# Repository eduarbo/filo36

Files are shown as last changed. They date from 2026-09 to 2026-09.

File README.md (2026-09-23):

# Flan36

**36 keys. Piantor angles. Your keycaps, your frames.**

**[Explore and customize in 3D →](https://eduarbo.github.io/flan36/)** · **[Parts and buying links →](docs/parts.md)** · **[Edit in FreeCAD →](docs/freecad.md)**

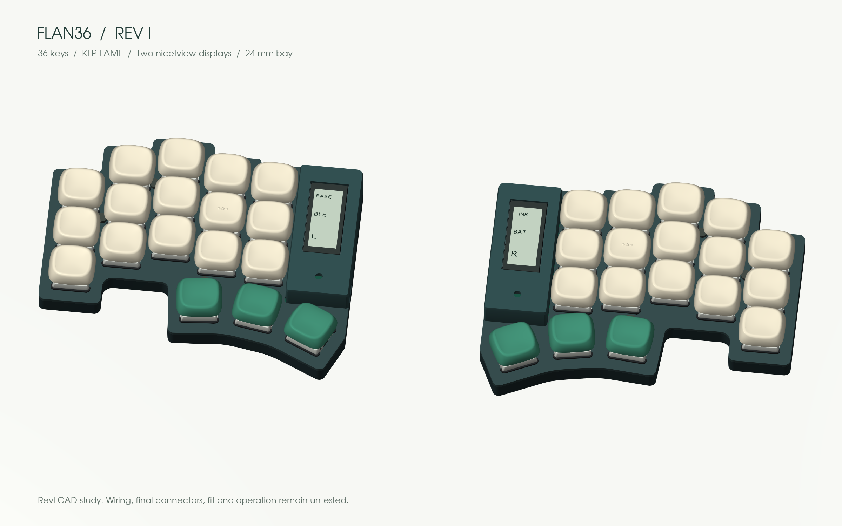
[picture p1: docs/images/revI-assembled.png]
Flan36 revI with interchangeable display frames and original KLP Lamé keycaps


*RevI: key-aligned local curves, three interchangeable cases, optional exposed display stack, magnetic frames and one cradle for two battery sizes. Physical fit untested.*

**[Themes and print kits](docs/themes-printing.md)** — Sixteen coordinated themes, personal keycap palettes, linked rim/frame colors and selected STL/3MF parts.

**[Case variants](docs/cases.md)** — Solid, Color rim and Terrace; actual meshes in the explorer.

Flan36 is a low-profile wireless split keyboard in development by [Eduardo Ruiz](https://github.com/eduarbo). It keeps Piantor’s key centers and angles, with five columns and three thumb keys per half.

- **KLP Lamé choices:** all 38 Choc-stem variants catalogued; 28 qualify in at least one position. The viewer checks complete combinations and exports a configuration for FreeCAD.
- **Magnetic frames:** Cartridge, Arcade, Mecha, Kintsugi, Handheld, Retro TV and Cyberpunk, with multicolor relief palettes, plus three plain styles and separate body colors per half. Opaque skirts hide the stack; the display has its own support.
- **Keycap colors:** paint all keys, rows, columns or individual keys; save and share your own palettes.
- **Free tools:** KiCad for electronics, FreeCAD for the case, StepUp for exchange. Editable source, STEP/STL, offline viewer and GLB included.
- **Intended hardware:** Choc v1 hot-swap, two nice!nano controllers and two nice!view displays. One display remains the fallback.

**Status: digital prototype, not ready to manufacture.** Both PCB studies have zero geometric DRC violations and 104 unconnected items each. Routing, exact connectors, printed retention, BLE and power consumption still require work. The visual model does not establish hardware compatibility.

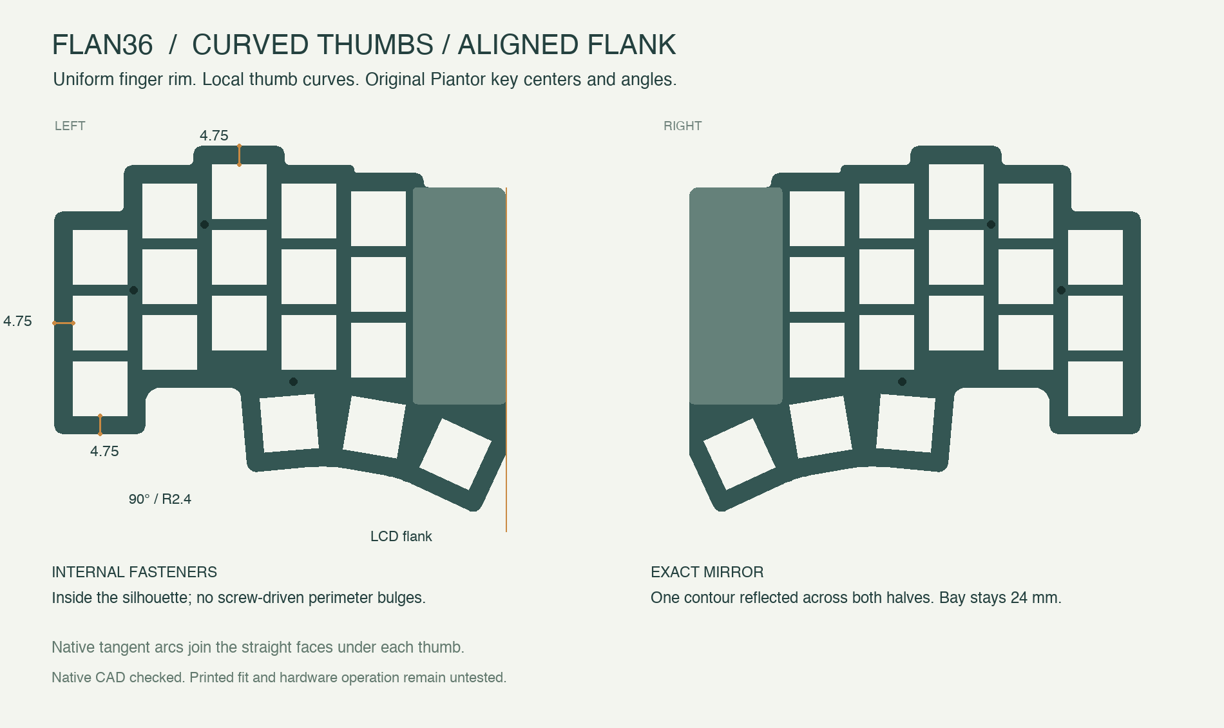
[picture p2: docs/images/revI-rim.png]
Measured rim and mirrored case halves


**[Keycaps and frames](docs/customize.md) · [Design](docs/design.md) · [Build](docs/build.md) · [CAD files](docs/cad.md) · [Progress](docs/progress.md)**

Based on [Piantor by beekeeb](https://github.com/beekeeb/piantor), with [KLP Lamé by braindefender](https://github.com/braindefender/KLP-Lame-Keycaps). [Credits and licenses](ATTRIBUTION.md). [Contributing](CONTRIBUTING.md).

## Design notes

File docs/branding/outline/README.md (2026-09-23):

# Flan36 Outline — SVG kit

The selected Outline concept is now an editable, font-free vector. Its symbol and six letters are closed filled Bézier paths; the four internal holes remain open. One chosen logo, supplied as a complete mark, symbol and lettering.

| File | Use | SVG page width |
| --- | --- | --- |
| `flan36-outline-master.svg` | Editable source; symbol and each letter have a named path | 30 mm |
| `flan36-outline-black.svg` | Complete logo, one ink; starting point for graphics import | 30 mm |
| `flan36-outline-symbol-black.svg` | Symbol alone, one ink; starting point for a small case/PCB mark | 12 mm |
| `flan36-outline-wordmark-black.svg` | Lettering alone, already converted to paths | 30 mm |

Backgrounds are transparent. `preview.svg` is a presentation sheet, **not** a manufacturing master; it presents the same logo on a light background. The logo SVGs have no fonts, raster images, live strokes, masks or external resources.

## PCB: KiCad

Import the black logo or symbol through **File → Import → Graphics**, set scale to **1**, select **F.SilkS** (or B.SilkS for a back-side mark), and group the imported items. Inspect the actual size and back-side orientation. Keep the mark clear of exposed pads, existing legends and mounting holes; check the fabricator's minimum line/space rules at the final scale. [KiCad graphics-import documentation](https://docs.kicad.org/10.0/en/pcbnew/pcbnew.html#importing-vector-graphics).

These are page widths with a tiny artboard margin, not approved placement dimensions. No logo is placed on the keyboard PCB by this kit. KiCad placement and final fabrication output still need checking.

## Case: FreeCAD

Import the black logo or symbol as **SVG as geometry (importSVG)**. The imported paths can form faces for an emboss or a pocket. Select the symbol alone for a compact mark, or all seven faces for the complete logo. [FreeCAD SVG workflow](https://github.com/FreeCAD/FreeCAD-documentation/blob/main/wiki/Import_text_and_geometry_from_Inkscape.md).

The supplied black logo, symbol and wordmark were imported headlessly into FreeCAD 1.1.3: dimensions, counters and valid trial extrusions were checked. This does not qualify a cut in a case wall. Choose the final placement and relief depth against the actual wall, ribs, battery and joining features. No case geometry is changed by this kit.

## Edit and regenerate

Edit `flan36-outline-master.svg` in a vector editor. For the repository generator, keep the seven named top-level paths, explicit absolute M/C/Z commands, no transforms and `fill-rule="evenodd"`; closed cubic contours keep the import path simple.

From the repository root, use a Python environment with `tools/requirements-branding.txt`:

```sh
python tools/build_outline_logo.py --png --package
python tools/check_outline_logo.py
python tools/freecad/run_macos.py tools/freecad/check_outline_logo.py
```

CairoSVG needs the Cairo system library for PNG rendering and raster readback. On macOS with Homebrew Cairo, prefix the first two commands with `DYLD_FALLBACK_LIBRARY_PATH=/opt/homebrew/lib`. The last command uses the existing macOS FreeCAD installation and opens no GUI. On other platforms, run `tools/freecad/check_outline_logo.py` in a FreeCAD Python environment.

`--trace` intentionally recreates the master from the selected concept and **replaces manual master edits**. Normal regeneration omits that flag. The vector trace uses the bottom-left monochrome reference from `docs/images/branding/flan36-caramel-outline.png`; earlier concept boards remain historical references.

The kit contains SVG art, this guide, a hash manifest and the repository license. It contains no placed PCB artwork, case cut, G-code or print-process approval. [Source and provenance](https://github.com/eduarbo/flan36/blob/main/design/branding-outline-vectors.json).

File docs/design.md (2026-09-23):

# Design

Keep Piantor’s angles, a thin key area and serviceable electronics.

| Choice | Reason |
|---|---|
| 3 × 5 + 3 keys per half | Remove the unused outer column without changing the remaining centers or angles |
| Choc v1 hot-swap | Low-profile, replaceable switches |
| Two nice!nano controllers, intended ZMK firmware | Wireless halves and host connection; USB-C for charging/programming |
| Battery below controller, display above | Concentrate electronics in the existing 24 mm bay |
| Independent internal supports | Neither the battery pouch nor display glass carries the stack |
| Interchangeable opaque display frames | Hide the stack and customize its appearance without moving keys |

## The stack

The insulating saddle stays below the PCB. The cell and a narrow removable cage pass through a **12.5 × 33.6 mm opening**. One cavity accepts the nominal Adafruit 1570 and 301230 envelopes; select either in the viewer or FreeCAD. The model reserves two 105 mm lead paths, but actual terminal positions, wire diameter and strain relief still need measurement. [Battery dimensions and sources](parts.md#battery).

The case is **116.75 × 94.57 mm per half**. Five stepped column tops, an orthogonal pinky foot and a shallow rounded recess follow the reference. Straight lower faces remain parallel to each thumb key, joined by **local tangent arcs**. The outside thumb flank stops at the LCD panel edge. The 21 control corners use locally bounded radii, including R2.4 finger corners where space permits. Straight exposed faces retain their **4.75 mm** copper allowance. Fasteners stay within existing material. Both halves are exact mirrors; all 36 switch centers and angles remain unchanged.

Choose [Solid, Color rim or Terrace](cases.md). These are different base/plate geometries, compatible with the same stack and ten display frames. The printed display cover can be omitted while retaining the display and structural supports.

Measured exterior rim

The key plate stays at **7.6 mm**, plain frames at **16.6 mm**, themed relief at **17.2 mm**. The electronics bay remains **24 mm wide**; illustrative feet add 1.2 mm. The frame ends at Y=67 mm while the low base/plate continue to the thumb. The power-switch reference is now recessed 0.1 mm inside the straight X=135 mm flank.

The frame now shares the case's **R2.4 north/outside corner** beside USB, including its tangency points. The former independent R1.2 frame corner projected about **0.497 mm** beyond that curve. The cavity, plate clearance and beveled lips follow the corrected corner; the case and PCB outlines stay unchanged.

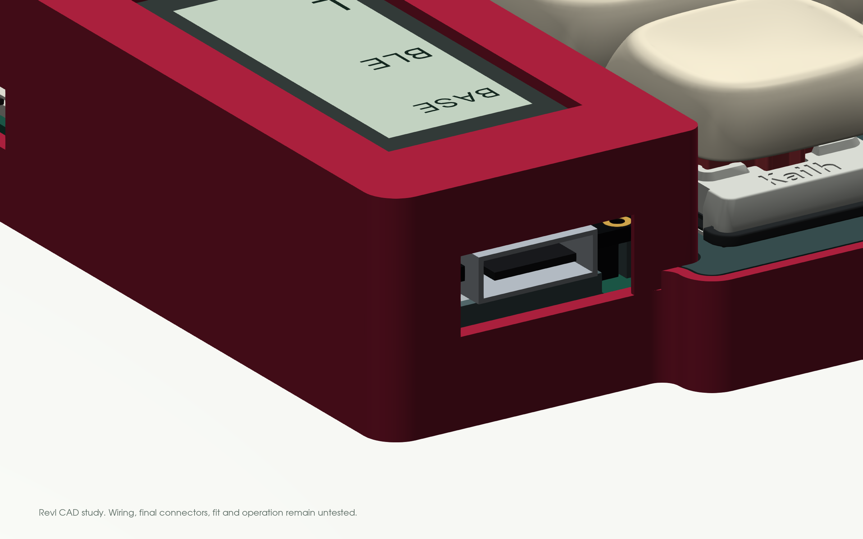
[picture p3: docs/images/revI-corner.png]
Shared corner on the actual Color rim and Smooth frame meshes


### Can the stack be thinner?

**The current height is not a proven minimum.** The completed
[slim support study](slim-mount-study.md) supersedes the preliminary left-half
height check: it covers both halves, all 10 frames and both battery profiles.
Dimensions below start at the case bottom, excluding feet.

| Configuration | Plain cover | Decorated cover | Status |
| --- | ---: | ---: | --- |
| Reference | 16.6 mm | 17.2 mm | Static modeled checks clear; retained |
| Lower display candidate | 15.6 mm | 16.2 mm | Static modeled checks clear; experimental |
| Rejected limit | 14.8 mm | 15.4 mm | Roof intersects the JST connector by 0.3 mm |

The lower candidate moves the display bottom from 14.2 to **12.4 mm**, leaving
**0.82 mm** between the modeled MCU and display and **0.5 mm** above the JST.
Actual header engagement and electrical continuity remain unqualified. With the
selected KLP Lamé keycaps, total height remains **17.87 mm** in all three
recipes; lowering the cover does not lower the highest point.

All three recipes have a service conflict: lifting the display and sled together
crosses the modeled battery leads at **0.5–2 mm**. Lead routing or the removal
sequence must change and be rechecked before physical qualification. The native
source retains the reference height.

Fusing the three washers into each plate removes **six loose parts** across the
keyboard while preserving their seats. Optional base/saddle fusion removes two
more, at the cost of independent saddle replacement. Both changes have **zero
height reduction**. [Study geometry and full findings](slim-mount-study.md) include
the rejected limit for comparison; printed fit remains unqualified. The
[earlier height report](../validation/revI-stack-study.json) remains as historical
evidence.

### Magnetic frame, independent structure

Three captive **Ø2 × 3 mm magnets** in the base attract three captive **Ø2 × 4 mm steel pins** in each frame. Shallow guides locate the cover; it lifts vertically. The frame carries no battery or display load. Five internal M2 fasteners per half retain the plate/PCB independently, with no added perimeter lobes. Three use 6 mm shafts; the two hidden under the frame use 4 mm shafts.

The inserts are enclosed by a pause-and-insert print sequence. Force through the nominal **0.9 mm gap**, north-edge peel, print capture and magnet temperature remain physical tests. [Assembly sequence and coupons](build.md#magnetic-frame-and-service).

## One or two displays

The CAD shows two nice!view displays; one on the left remains the fallback if integration becomes impractical. The intended central display shows primary keyboard state. A peripheral display may show its own battery/link state; mirrored layer information is not promised. [nice!view setup](https://nicekeyboards.com/docs/nice-view/getting-started/).

nice!view is a reflective memory LCD. OLED improves dark-room visibility but uses more power; e-paper favors mostly static images and needs different mounting and firmware. These are alternatives to redesign around, not drop-in replacements. [Display specifications](https://nicekeyboards.com/docs/nice-view/).

## Modularity

Switch sockets, removable controller/display connectors, a battery connector, magnetic covers and independent screws allow servicing after initial soldering. The frames are separate from the display support. Service electronics with power off and USB disconnected; removable connectors are not a proposal for live module hot-plugging.

## CAD views

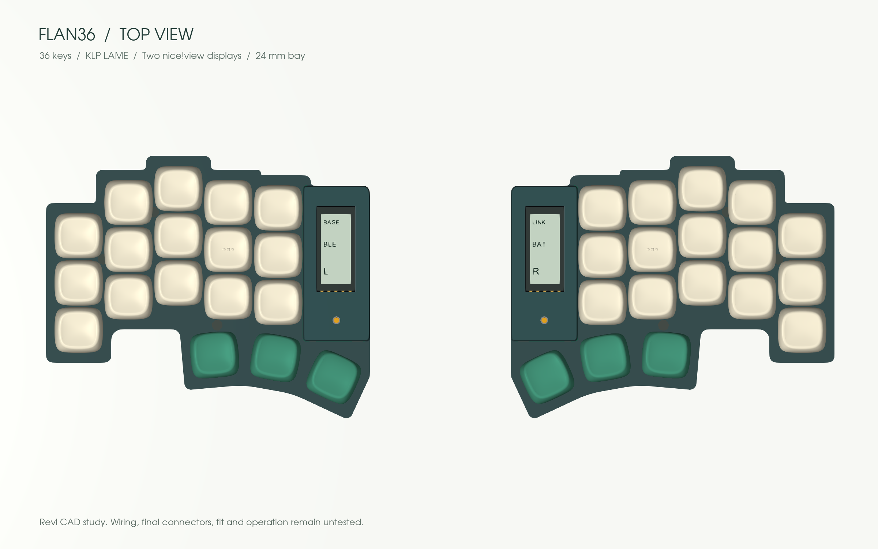
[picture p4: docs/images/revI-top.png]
RevI top view with 36 KLP Lamé keycaps and two display frames


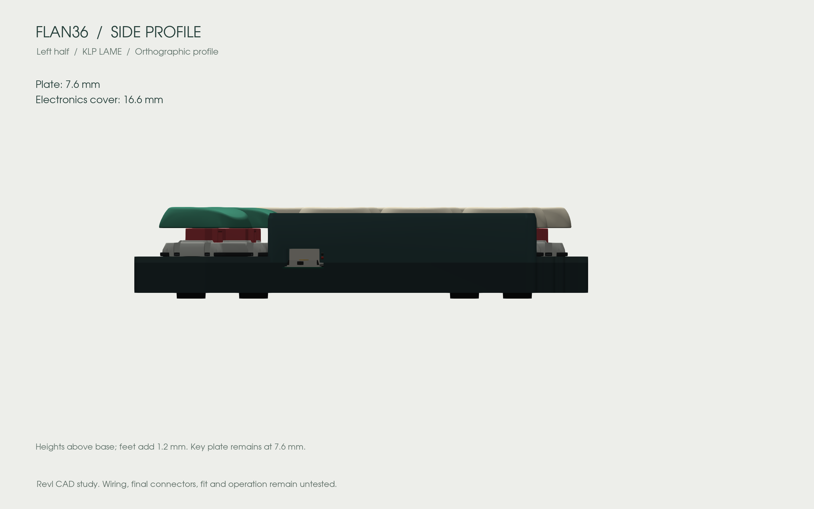
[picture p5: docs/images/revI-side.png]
RevI side profile


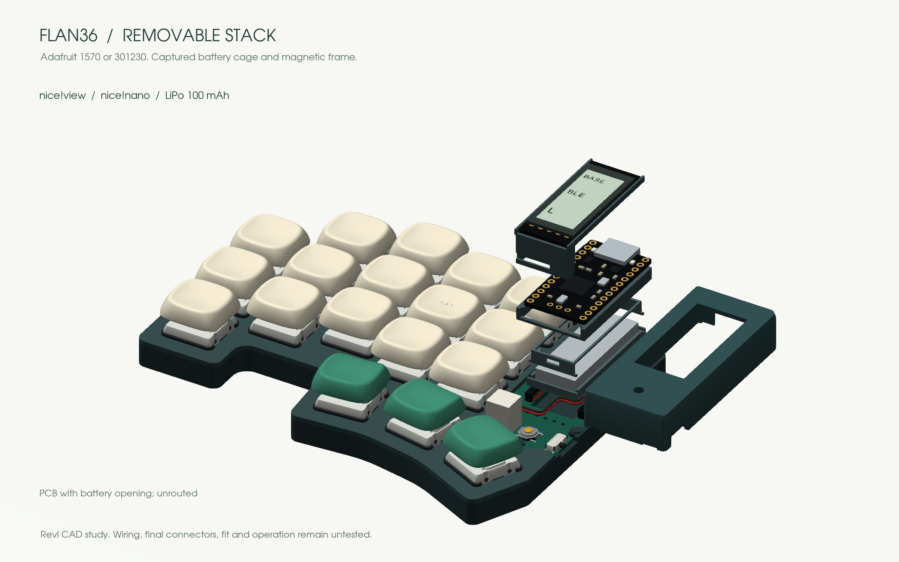
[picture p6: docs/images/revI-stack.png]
RevI exploded stack with removable opaque cover


These views come from the exported geometry. Electronics, switch bodies, keycap seating, screws and feet are nominal references. No physical assembly or functioning keyboard is established by the renders. [Source files and remaining work](cad.md).

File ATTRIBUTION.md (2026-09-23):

# Credits and licenses

Flan36 is a derivative project developed by Eduardo Ruiz. Its case and wireless electronics are developed here; its key layout comes from Piantor. There is no implied affiliation or certification by beekeeb or component manufacturers.

| Material | Author / source | License and changes |
|---|---|---|
| `sources/piantor/*.kicad_pcb` | beekeeb / Leo, [Piantor](https://github.com/beekeeb/piantor), commit `cd847afb4f9a86e8c1c8e36f243140644013afb2` | GPL-3.0; unchanged original copies |
| Choc footprint `keyswitches:Kailh_socket_PG1350_optional` | daprice, [keyswitches.pretty](https://github.com/daprice/keyswitches.pretty) | CC-BY-SA-4.0; notice in [LICENSES/Keyswitches.md](LICENSES/Keyswitches.md) |
| `Keebio-Parts:TRRS-PJ-320A` footprint | [Keebio](https://github.com/keebio/Keebio-Parts.pretty), commit `063565dcba9a8ee807d49772de0ed75ecaedcc26` | MIT; copyright/permission in [LICENSES/Keebio-MIT.txt](LICENSES/Keebio-MIT.txt) |
| `RPi_Pico:RPi_Pico_SMD_TH` footprint | [TPCWare / Nicola Carandini](https://github.com/ncarandini/KiCad-RP-Pico), commit `dc6f9b9f213dc36eebce626aa9ee72a333fa0db3` | [TPCWare license](LICENSES/TPCWare-KiCad.txt): CC-BY-SA-4.0 with design exception |
| Standard KiCad footprints, including `Resistor_SMD:R_1206_3216Metric_Pad1.30x1.75mm_HandSolder` | [KiCad libraries](https://www.kicad.org/libraries/license/) | [CC-BY-SA-4.0 with design exception](LICENSES/KiCad-Libraries.md) |
| `design/layout.json`, layout diagram | Derived from Piantor coordinates | GPL-3.0; outer column removed and origin translated, relative centers and angles retained |
| `keycaps/*.stl`, `keycaps/variants/*.stl`, KLP meshes in FCStd/viewer/GLB | [KLP Lamé by braindefender](https://github.com/braindefender/KLP-Lame-Keycaps), commit `4a67a824232d3054c61599ea047c56a340faaba2` | CC-BY-SA-4.0; unchanged meshes, placed and colored. RevG catalogs all 38 Choc-stem files, Choc/MX body sizes. [Original three sources](keycaps/sources.json), [complete pinned sources](keycaps/variants-source.json) |
| `docs/images/revE-*.png` through `revI-*.png`, including case screenshots | Flan36 CAD renders incorporating Piantor-derived design and KLP Lamé | CC-BY-SA-4.0; calculated from attributed meshes, no image retouching |
| Derived CAD, project tools and original documentation | Eduardo Ruiz / Flan36 contributors | GPL-3.0-or-later, except identified materials above |
| Embedded 3D engine | [Three.js](https://github.com/mrdoob/three.js), 0.180.0 | MIT; full [notice](LICENSES/Three-MIT.txt) also embedded in offline HTML |
| External product photos in the parts guide | Typeractive, Adafruit and respective rights holders | Linked/embedded from supplier listings; not copied into the asset tree or relicensed under the repository license |

The viewer retains source notices; exported GLB includes attribution and source/license links. Viewer code is under GPL-3.0-or-later; esbuild is a pinned build dependency. Gzip packaging does not alter the underlying geometry.

The three `docs/images/branding/flan36-*-concept.png` boards were generated with OpenAI's built-in image generation tool for Eduardo's Flan36 identity exploration. They are concept art, not renders of the measured CAD. Four additional Caramel refinements (`flan36-caramel-soft.png`, `flan36-caramel-drop.png`, `flan36-caramel-bold.png`, `flan36-caramel-outline.png`) use the selected Caramel board as their reference. Prompts and provenance are retained in `design/branding-prompts.json`, `design/branding-caramel-prompts.json` and `design/branding.json`; their reuse follows the repository's GPL-3.0-or-later terms to the extent applicable.

Full texts: [GPL](LICENSE), [CC-BY-SA-4.0](LICENSES/CC-BY-SA-4.0.txt). Original upstream hashes: [sources/manifest.json](sources/manifest.json).

Libraries under `hardware/revF/libraries` contain KiCad sources with the design exception, daprice’s Choc footprint under CC-BY-SA-4.0, and Flan36 symbols/footprints. STEP files under `hardware/revF/models` are original nominal envelopes, not manufacturer-certified models.

FreeCAD, StepUp, ZMK, Zephyr, nice!nano and nice!view retain their own names/licenses. FreeCAD/StepUp are installed separately; firmware binaries are not distributed here. Supplier links do not imply sponsorship.

## Commercial component representations

KiSwitch Choc v1 source CAD is used under its MIT option (copyright 2019–2022 keyswitch-kicad-library contributors). KiCad PCM12, TL3342 and SOD-123 assets use CC-BY-SA-4.0 with the KiCad library exception. See [per-file sources, transformations and limits](components/README.md) and [asset hashes](components/sources.json). nice!nano v2 is an original nominal reconstruction referenced to official photographs and the Woovie community drawing; no official photograph is embedded or relicensed.

The `docs/branding/outline/flan36-*.svg` artwork is a deterministic vector conversion of the selected Outline board’s monochrome reference. Letterforms are traced paths, not a bundled or substituted font. Source, reference hash and contour checks are recorded in `tools/build_outline_logo.py`, `validation/branding-outline-trace.json` and `design/branding-outline-vectors.json`. The preview and SVG kit follow GPL-3.0-or-later to the extent applicable.

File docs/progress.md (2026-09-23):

# Progress

**Current mechanical revision: I. Overall keyboard: partial digital prototype.**

| Outcome | State | Evidence / next step |
|---|---|---|
| 36 Piantor key centers and angles | Checked | [Layout](../design/layout.json), upstream files and checker |
| Editable source and CAD exchange | Available | Native FCStd, parameters and [FreeCAD/StepUp examples](freecad.md) |
| KLP catalog and themed frames | RevI digital study | 38 source variants, 28 with qualified positions; ten frame styles, per-key colors and configuration export/import |
| Wireless electronics and displays | Placement only | Unrouted revI PCBs; 0 geometric DRC violations, 104 unconnected items each; exact connectors pending |
| Final BOM and manufacturing files | Pending | Close routing, clearances, retention and exact supplied parts |
| Printing and assembly | Pending | Fit coupon, sample caps and actual component measurements |
| Working keyboard | Pending | All keys, BLE, charging, sleep/wake and measured consumption |

## Revision I — keycap palettes and creative frames

Color all keys, a row, a column or one key, on either half or both. Eight keycap palettes and sixteen coordinated global themes provide starting points. Personal palettes can be saved, imported and exported; configurations retain all 36 colors without changing key shapes or rotations. [Color editor](customize.md#keycap-colors).

Cartridge, Arcade, Mecha and Kintsugi bring the frame catalog to ten. Their relief is actual printable geometry; previews and print kits use the corresponding meshes. Native FreeCAD preserves custom colors through save/reopen. [Frame guide](frames-extra.md).

The [measured support study](slim-mount-study.md) covers both halves, both batteries and all ten frames. Integrating plate washers removes six loose parts; optional integrated battery saddles remove two more. Neither changes height. A 15.6 mm plain roof clears modeled static geometry, but overall height stays **17.87 mm** with the selected caps, excluding feet. A 14.8 mm roof intersects the JST envelope. Display/sled extraction crosses modeled battery leads in all three recipes; cable routing, connector engagement and physical fit remain open. Separately named experimental STEP/STL files are included; the reference print kit keeps its original stack.

Publication verified: all **1,013 implementation files** match the anonymous archive. The public viewer passes desktop/touch checks, per-key palettes, coordinated themes, configuration/GLB round trips and six selected print kits. [Public readback](../validation/revI-customization-publication.json). Physical keyboard acceptance remains open.

## Revision I — shared frame corner and height study

The USB-side frame corner now uses the case's actual R2.4 arc. The previous R1.2 frame produced a roughly 0.497 mm diagonal overhang. The cavity, plate clearance and beveled profiles follow that shared definition. Case/PCB outlines and key positions are unchanged. [Close view and height comparison](design.md#can-the-stack-be-thinner) · [Native corner check](../validation/revI-frame-corner.json).

The current 16.6 mm plain / 17.2 mm decorated cover is **not a proven minimum**. A preliminary left-half study lowers the display and evaluates 15.6 / 16.2 mm covers; actual connector engagement and tolerances remain open. A 14.8 mm plain cover intersects the existing battery-connector envelope. Printable source heights remain unchanged. [Study](../validation/revI-stack-study.json) · [Correction scope](../design/corner-stack-workflow.json) · [Independent review](../validation/revI-corner-stack-review.json).

Publication verified: all **922 implementation files** matched the anonymous archive; public Pages, the corner image, desktop/touch UI and selected print exports matched the tested source. [Public readback](../validation/revI-corner-stack-publication.json).

## Revision I — linked colors, print kits and component models

Sixteen color themes coordinate the frame with the case rim. Per-half body, plate and three detail colors survive JSON and local browser storage; applying a theme preserves the selected shapes and keycaps. Print kits include the selected native STL parts, generic color 3MF files, supports, washers and the actual screw/magnet instructions. No clip variant is claimed. [Themes and printing](themes-printing.md).

The nice!nano v2 and nice!view now have nominal board/contact/package geometry. Choc v1 uses licensed KiSwitch meshes; the power and reset switches use KiCad models placed at the existing footprints. The narrower nano board uses scalloped support ledges, leaving the underside pad reserves clear. [Component evidence and limitations](../components/README.md).

The offline explorer passed desktop/touch emulation down to 320 px, per-half configuration and custom-color GLB export. Native FreeCAD preserved colors through save/reopen. Selected print kits preserve native STL bytes and closed, oriented 3MF surfaces. [Configuration checks](../validation/revI-theme-customization.json) · [Print checks](../validation/revI-print-kit.json).

With 4× CPU throttling, orbit p95 is **16.7 ms**, frame choice **68 ms** and case choice **124 ms**, with no orbit long tasks. First readiness takes **8.7 s** in this local stress test; the self-contained viewer is about **45 MiB**. Physical-phone loading and timing remain unmeasured. [Measurement](../validation/revI-theme-performance.json).

Publication verified: all **914 implementation files** matched the anonymous source archive. The actual public viewer passed desktop/touch emulation, 16 theme previews, linked colors, JSON/GLB and selected print-kit checks. All 11 relative KiCad STEP models passed geometry, footprint-placement and colored-surface readback. [Public verification](../validation/revI-themes-components-publication.json).

**Still partial:** Bambu Studio needs manual palette mapping; GUI import/save/reopen has not been validated. Hotswap socket registration, actual connector contacts, the 7 versus 8.8 mm display connection and physical fit remain open. [Scope and review](../design/themes-components-workflow.json).

## Revision I — local curves and interchangeable cases

The contour now follows each thumb’s angle with local tangent rounds, plus softer finger corners. Solid, Color rim and Terrace are real base/plate variants. Per-half choices and optional exposed display stacks transfer between the explorer, JSON, GLB and native FreeCAD. [Case gallery and files](cases.md) · [Decision record](../validation/revI-case-variants-review.json).

Native solids, all six case pairs, mixed configuration save/reopen and exact selected GLB meshes passed. The explorer uses distinct mesh previews in a two-column grid; desktop and touch emulation pass through 320 px. Local 4× CPU checks: orbit p95 **16.8 ms**, case selection p95 **123.5 ms**, frame selection p95 **68.6 ms**, zero orbit long tasks. Publication verified: **824 source files** match the anonymous archive; public viewer, case gallery images, desktop/touch interactions, per-half case selection, open covers and exact JSON/GLB exports pass. [Public readback](../validation/revI-case-variants-publication.json). Physical-phone timing and printed fit remain untested.

## Previous revision I — uniform exposed rim

That revision made the case, switch plate and PCB follow a **curved lower thumb edge and LCD-aligned flank**. The 2.55 mm thumb-side protrusion is removed without moving keys or widening the bay. Finger margins stay 4.75 mm; the pinky foot retains 90° backbone corners with R0.8 blends. View tools remain below the model, with clearer Part links/Fit view feedback and full-row explorer hover. [Measured view](images/revI-rim.png) · [Correction review](revI-review.md#key-aligned-local-curves-and-case-variants).

Publication verified: **785 source files** match the anonymous download. The public viewer passes desktop/touch emulation, layers, frame/battery selection, JSON and exact GLB checks; the dimensioned image matches its source. [Public readback](../validation/revI-rim-publication.json).

That revision’s local viewer check: 4× CPU orbit p95 **16.7 ms**, theme change p95 **64.6 ms**, and zero orbit long tasks. Desktop/touch emulation, layers, JSON and exact GLB exports pass. Physical-phone timing remains unmeasured.

## Earlier revision I — Contour, magnetic frames and dual battery cradle

The case and PCB follow the stepped reference: rectangular pinky foot, shallow recess and continuous thumb fan. The **117 × 92.85 mm** case uses 20 control corners at R0.8. All 36 original key transforms remain fixed.

Three captive magnet/steel stations release each frame vertically; five independent internal M2 screws retain the structure without adding perimeter lobes. Both nominal **Adafruit 1570 and 301230** envelopes share one low saddle, aperture and captured cage. The viewer and FreeCAD configuration include battery selection.

The viewer passed offline desktop and emulated mobile checks, exact selected battery/frame GLB exports and JSON round trips. Local 4× CPU measurements: **16.8 ms orbit p95**, **67 ms frame-change p95**, zero orbit long tasks. Physical-phone performance remains untested.

The earlier slot/copper conflict and displaced mount were corrected without relaxing the 0.5 mm edge rule. Native solids, six frame styles, two battery envelopes, saved configurations, CAD-derived renders and the viewer are checked as digital artifacts. Routing, connector qualification, printed retention, charging and BLE remain open.

Publication verified: all **775 source files** matched the anonymous archive; public viewer bytes and actual browser-loaded geometry matched the tested source. Desktop/touch emulation, batteries, frames, JSON and exact selected GLB geometry passed. [Public readback](../validation/revI-publication.json).

[Review and limits](revI-review.md) · [Mechanical checks](../validation/revI-mechanical.json) · [PCB readback](../validation/revI-electrical.json) · [Service/coupons](../validation/revI-service.json).

## Multicolor frame previews

Handheld, Retro TV and Cyberpunk now use distinct body, detail and accent colors on the existing raised faces. Larger upright previews show the corresponding meshes and palettes; one click applies both. Body-color overrides remain independent per half and survive JSON export/import. The shared palette also drives the GLB materials, FreeCAD configuration import and frame comparison image.

The former thumbnails referenced different STL files, but used one green material and a distant oblique view. Their distinct-image test did not establish readable design details. Current checks identify actual left/right raised features, preserve every original vertex/normal/triangle and verify the exported material colors. Geometry and manufacturing status remain unchanged.

Verified on the public viewer, including mobile emulation, JSON and GLB; all 579 published source files matched the tested commit. FreeCAD applied four colors per native theme/half and preserved them through save/reopen. The 4× CPU benchmark retained a 16.7 ms orbit p95 and 57.5 ms theme-change p95.

[Color and print guide](customize.md#print-a-themed-display-frame) · [Checks](../validation/viewer-multicolor.json) · [Public readback](../validation/viewer-multicolor-publication.json) · [Correction scope](../design/viewer-multicolor-workflow.json).

## Persistent component sidebar

All 12 component entries remain visible while their details scroll or collapse. Hover, focus or select a part to highlight it; the connecting line ends at its own sidebar entry. Frame previews still apply in one click. Desktop, 390 px and 320 px touch layouts, short landscape, configuration and exact GLB export passed local and public checks.

The previous floating-tag iteration passed functional tests but missed the intended sidebar relationship and had no latency acceptance. Its anchor search could run up to 192 full-scene intersection queries per camera update. Surface searching now pauses during gestures and resolves only the active component afterward; rendering is coalesced and highlights are reused.

On the same Chromium 152 setup at 1200 × 800 with 4× CPU throttling, **p95 orbit frame interval fell from 1,616.5 to 16.8 ms**, with 59 long tasks reduced to zero. **Frame-change p95 fell from 1,692.4 to 59.0 ms**. These are local benchmark results; physical-phone performance remains untested.

[Usage guide](viewer.md) · [Checks and measurements](../validation/viewer-sidebar.json) · [Public readback](../validation/viewer-sidebar-publication.json), including all 571 source-commit files · [Correction scope](../design/viewer-sidebar-workflow.json). Historical acceptance of the first visual explorer remains in its [original receipt](../validation/viewer-ux-publication.json).

## Revision H — continuous edge and printable themes

The user’s red-line reference replaces the old display notch and thumb wing with one straight inner case flank. The case is approximately **8.1 mm narrower**, keeping every switch center and angle. Sixteen intentional corners use a common **1.2 mm radius**.

Handheld, Retro TV and Cyberpunk add actual roof relief within the same bay. Plain styles remain available. The high cover ends before the thumb; base and plate continue the aligned edge. Both KiCad contours match the new CAD reference without moving footprints or changing nets. There are still **26 DRC violations and 104 unconnected items per half**.

Publication verified: all **561 source files** matched the anonymous archive. Public HTML and the browser-loaded scene matched the tested source; layers, orbit, all three themes, JSON, selected GLB geometry and narrow-screen emulation passed. Actual phone and hardware tests remain pending. [Publication receipt](../validation/revH-publication.json).

[Revision review](revH-review.md) · [Keycap checks](../validation/revH-keycaps.json) · [Mechanical checks](../validation/revH-mechanical.json).

## Revision G — keycaps and frames

Opaque covers replace revF’s side rails. The separate display sled stays in place. Smooth, beveled and faceted styles share the same mounting centers, inner cavity and service openings. Bay width and top height remain 24 and 16.6 mm.

The viewer selects KLP variants by position/orientation, checks complete combinations and writes a JSON configuration used by the FreeCAD macro. GLB exports carry the active configuration. The cap check is separate from solid-part collision checks, which did not include KLP meshes in revF.

Documentation, current CAD labels, viewer and new render captions are in English. The [parts guide](parts.md) separates references from alternatives and adds technical links, supplier photos and Typeractive pack quantities. Conflicting part numbers and missing exact datasheets are kept visible.

Publication verified: an anonymous archive matched all **404 files** of the design commit; public viewer bytes matched the tested source. Keycap/frame selection, JSON round trip, exact selected GLB vertices, layers, rotation and narrow-screen behavior passed on the public URL. [Publication receipt](../validation/revG-publication.json).

[Review and limits](revG-review.md) · [Keycap checks](../validation/revG-keycaps.json) · [Mechanical checks](../validation/revG-mechanical.json).

## Earlier revisions

- **RevD:** wide side-by-side electronics and one display; visual direction discarded. The render survives only in Git history.
- **RevE:** 24 mm stacked bay, two displays and a 19 mm cover. CAD-derived images replaced the stale revD render.
- **RevF:** recessed battery opening, moved controller/display and 16.6 mm open rails. Native FreeCAD source added. Approximate case depth became 94.5 mm; width remained 126.2 mm because the thumb layout stayed unchanged.

RevF’s CAD/StepUp exchange, anonymous source download and public viewer were checked; physical acceptance was not. [Historical review](revF-review.md) · [publication receipt](../validation/revF-publication.json).

On September 22, 2026, Eduardo selected **Flan36** and the **Outline** logo. The current presentation shows only that selection. On September 23, the rename was extended to the repository, Pages site, current native filenames and new configuration exports. Legacy configuration imports remain supported. Geometry and unfinished electrical/physical requirements are unchanged.

The LCD-flank/curved-thumb and viewer correction is published. Anonymous source readback verified all **788 implementation files**; public browser checks passed for individual visibility, Solo/Show all, temporary X-ray hover, fixed View controls and mobile layouts. [Publication receipt](../validation/revI-lcd-curve-publication.json). Physical assembly and electronics acceptance remain open.

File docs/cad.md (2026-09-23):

# Editable CAD and 3D files

**[Editing guide](freecad.md)** · **[3D configurator](https://eduarbo.github.io/flan36/)** · **[Configuration format and examples](customize.md)**

The current mechanical source is [`mechanical/revI/Flan36.FCStd`](../mechanical/revI/Flan36.FCStd). It contains both halves, native sketches/operations, editable parameters and 36 original KLP meshes. Commercial modules use [nominal component models](../components/README.md); some connectors remain dimensional reserves. The matching revI KiCad studies use the chosen contour and internal battery/magnet clearances. Six auxiliary/mounting footprints move; all key transforms and nets are preserved.

| Nominal measure | Revision I |
|---|---:|
| Frame maximum height | 16.6 mm plain / 17.2 mm themed |
| Display glass top | 16.1 mm |
| Key plate top | 7.6 mm |
| Electronics bay | 24 mm |
| Case width × depth, each half | 116.75 × 94.57 mm |
| Case control corners / radius | 21 / locally bounded tangent arcs |
| Exposed finger switch-to-rim margin | 4.75 mm |
| Battery aperture | 12.5 × 33.6 mm |
| North overhang past adjacent cap | 0 mm nominal |

Heights exclude the illustrative 1.2 mm feet. USB is only 0.045 mm behind the adjacent keycap’s north edge: this is a nominal alignment, not a physical tolerance guarantee.

## Files

- `mechanical/revI/Flan36.FCStd`: editable assembly.
- `mechanical/revI/*-case-{solid,rim,terrace}-{base,plate}.{step,stl}`: [three real case variants](cases.md).
- `mechanical/revI/*-assembly.step`: installed solid parts per half; no KLP mesh bodies.
- `mechanical/revI/*-frame-{smooth,bevel,facet,handheld,tv,cyberpunk,cartridge,arcade,mecha,kintsugi}.{step,stl}`: all interchangeable cover styles.
- `mechanical/revI/*.step`, `*.stl`: individual prototype parts and identified envelopes.
- `mechanical/revI/*-battery-{adafruit-1570,301230}.stl`: selectable nominal cell envelopes.
- `mechanical/revI/coupon-*.{step,stl}`: actual magnetic/thread interface samples.
- `keycaps/variants/`: all 38 unchanged Choc-stem KLP files, including unqualified study variants.
- `keycaps/catalog.json`: provenance, actual stem axes, convex envelopes and qualification.
- `design/configurations/`: default and two sculpted preset examples.
- `hardware/revI/`: two KiCad projects, schematic/PCB placement, local libraries and models; **unrouted**.
- `docs/images/revI-*.png`: renders calculated from exported meshes.
- Viewer: self-contained offline HTML, active-configuration GLB and JSON downloads.

Parts retain assembly coordinates. Screw envelopes and nominal engagement are modeled; physical fits, printing orientation and final slicing settings are not qualified. Historical revE/revF/revG/revH sources and receipts remain available for comparison. To rebuild an older viewer, use its historical Git commit; the current shared viewer code targets revI.

## Rebuild the reference

These commands overwrite generated revI reference files. **Do not run them over a source you edited by hand.** Use a separate checkout for reconstruction and keep custom FCStd files elsewhere.

Tested tooling: FreeCAD 1.1.3, KiCad 10.0.6, StepUp 13.1.7 (package metadata 11.09.6), Python with `tools/requirements-render.txt`, and Node dependencies fixed in `viewer/package-lock.json`.

```sh
python -m pip install -r tools/requirements-render.txt
npm ci --prefix viewer
python tools/build_revI_profiles.py
python tools/build_revI_wire.py
python tools/build_keycap_catalog.py
python tools/check_revI_config.py
python tools/check_revI_fasteners.py
FILO_QT_PLATFORM=cocoa python3 tools/freecad/run_macos.py tools/freecad/export_switch_models.py
FILO_QT_PLATFORM=cocoa python3 tools/freecad/run_macos.py tools/freecad/build_revI.py
FILO_QT_PLATFORM=cocoa python3 tools/freecad/run_macos.py tools/freecad/check_components.py
FILO_QT_PLATFORM=cocoa python3 tools/freecad/run_macos.py tools/freecad/export_pcb_components.py
FILO_QT_PLATFORM=cocoa python3 tools/freecad/run_macos.py tools/freecad/check_revI_service.py
FILO_QT_PLATFORM=cocoa python3 tools/freecad/run_macos.py tools/freecad/check_revI.py
FILO_QT_PLATFORM=cocoa python3 tools/freecad/run_macos.py tools/freecad/check_revI_rim.py
FILO_QT_PLATFORM=cocoa python3 tools/freecad/run_macos.py tools/freecad/check_cases.py
FILO_QT_PLATFORM=cocoa python3 tools/freecad/run_macos.py tools/freecad/check_frame_corner.py
FILO_QT_PLATFORM=cocoa python3 tools/freecad/run_macos.py tools/freecad/study_stack_height.py
FILO_QT_PLATFORM=cocoa python3 tools/freecad/run_macos.py tools/freecad/check_finishes.py
python tools/render_revI.py
python tools/render_frames.py
python tools/render_rim.py
python tools/build_viewer_revI.py
node viewer/build.mjs
python tools/check_viewer_revI.py
python3 tools/check_layout.py
node viewer/check.cjs
node viewer/customize-check.cjs
python tools/check_print_kit.py
cp build/viewer-multicolor/freecad.json validation/revI-freecad-finishes.json
cp build/themes-print/ui.json validation/revI-theme-customization.json
cp build/themes-print/print-validation.json validation/revI-print-kit.json
cp build/themes-print/themes-desktop.png docs/images/revI-themes.png
cp build/themes-print/nano-v2.png docs/images/revI-nano-v2.png
python3 tools/check_parts_links.py
python3 tools/check_rebrand.py
```

To regenerate the current PCB without replacing existing work, use `python3 tools/build_revI_pcb.py --output build/lcd-curve/hardware` with a new empty destination and compare its two PCB files. The source remains the immutable revH placement.

For a fresh PCB reconstruction, run `python3 tools/build_revI_pcb.py` only when `hardware/revI/` does not exist. Run KiCad CLI DRC for both boards with JSON outputs at `build/revI/drc-left.json` and `drc-right.json`, then run `tools/check_revI_pcb.py` with KiCad Python. It checks the explicitly allowed footprint changes, preserved keys/nets and exact new outline, and writes the actual pad polygons. Then run `python tools/check_revI_outline.py` to measure every pad-to-edge clearance. Run these PCB checks before the final delivery check.

The macOS helper uses an existing FreeCAD installation. It disables optional `flatmesh` only in its subprocess because that installed extension crashes on import; it does not modify application preferences. The helper defaults to offscreen Qt. The full-rebuild commands above retain the earlier explicit Cocoa path; the current frame installer and key-color roundtrip use offscreen GUI support to preserve native appearance without showing a window. On other systems, run the scripts through the equivalent installed FreeCAD Python environment.

After an authorized publication, `python3 tools/check_public_delivery.py COMMIT_SHA` checks an anonymous full source ZIP against every Git blob and compares public Pages with that commit. Its ZIP and receipt are reproducible under `build/revI/`; it does not publish anything.

The corner check inspects all 12 saved frame bodies against the native case outline and rejects the former R1.2 overhang. The height study changes only an in-memory document, checks affected left-half pairs at two candidate heights and writes its receipt without saving the CAD source. It does not qualify connectors or select a printable configuration. `build/corner-stack/` contains ignored regenerable logs and staging for these commands.

The browser check needs Playwright and a Chromium-compatible browser. Set `FLAN36_PLAYWRIGHT_MODULE` and `FLAN36_BROWSER` if they are not on the usual path. It tests the generated file with HTTP(S) requests blocked; `FLAN36_VIEWER_URL` instead selects the published URL.

The native configuration test also uses the scoped subprocess exit after its assertions, file writes and save/reopen readback to avoid the same Qt teardown crash. It does not suppress failed assertions or change installed FreeCAD.

The catalog build verifies SHA-256 and Git blob hashes of every pinned upstream STL. The geometry exporter checks closed printable solids, pair intersections, all three case pairs, both cell variants and all ten cover variants against components and a nominal USB plug corridor. The case checker measures the actual saved solids at the side bands, floor and raised-rim joint. The separate keycap checker includes complete-configuration envelopes and a travel/plate bound. The service checker samples frame lift, checks closed insert capture, cage capture and the cell-motion bound against lead paths. These tests do not measure force or print tolerances. Source hashes and results are under `validation/revI-*`.

`build/` is ignored and reproducible: native save/reopen trials come from `check_revI.py`; screenshots, test GLB/JSON and UI receipts from `viewer/check.cjs`; the viewer scene from `build_viewer_revI.py`. Source generations should be compared geometrically because STEP/FCStd metadata may vary. DRC JSON and pad polygons regenerate with the PCB checks above; service coupons regenerate with `check_revI_service.py`. The rim checker rejects the retained former contour, measures 216 preserved finger/outer-thumb normal samples, verifies native local tangent arcs and LCD-aligned flanks in the actual plate solids, and compares mirrored tray/plate volumes. `tools/check_revI_fasteners.py` clips actual KLP triangles to each screw-height travel slab for all 756 qualified reference choices. `build/case-variants/`, `build/lcd-curve/` and `build/uniform-contour/` contain reproducible logs/staging from these commands; review decisions are retained in the public receipt. The disposable contour study and reference copy in `build/case-variants/` are removed after acceptance; case screenshots and selected JSON/GLB regenerate with `viewer/check.cjs`. `viewer/performance.cjs` regenerates the current interaction timing receipt under `build/viewer-sidebar/`; `viewer/finishes-check.cjs` checks triangle/material identity. The native finish checker saves its current readback under `build/viewer-multicolor/freecad.json`.

## PCB exchange

The existing relative STEP references in `hardware/revI/models/` use the current nominal nano, display, connector, power/reset switch and Choc geometry. Their colors and footprint registration are checked by exporting and reimporting all 11 models. This update does not alter the PCB files, footprints or nets. [Model readback](../validation/revI-pcb-component-models.json).

RevI updates the board contour, battery opening and magnetic-station cutouts. `tools/build_revI_pcb.py` copies the historical unrouted source and refuses to overwrite existing work. Readback permits only H1/H3/H4/H5, J1 and SW1 to move; it checks preserved pad/net/drill/UUID/model data and all 36 locked keys. The verified StepUp procedure and coordinate alignment are described in [the editing guide](freecad.md#3-inspect-the-pcb-with-stepup). To rerun the historical exchange test on temporary copies:

```sh
FILO_QT_PLATFORM=cocoa python3 tools/freecad/run_macos.py tools/freecad/check_stepup.py
```

Then run `tools/check_stepup_readback.py` with KiCad’s Python. The StepUp harness exits its own GUI subprocess after saving because that runtime crashes during Qt teardown; independent KiCad readback is required. The test must change only the example opening edge, without altering key positions, pads, connectivity or the outer contour.

`tools/sync_pcb_study.py` resets reference placement; it is not an automatic synchronizer for hand-edited designs. Never use it to discard routing. The current contour/DRC receipt is [revI-electrical.json](../validation/revI-electrical.json); the full schematic/netlist validation is retained as historical [revF-electrical.json](../validation/revF-electrical.json).

## Remaining hardware work

The battery opening now leaves approximately **0.524 mm minimum measured pad clearance**, above the configured 0.5 mm rule. Both boards have **zero geometric DRC violations and 104 unconnected items each**. They remain unrouted; do not order them as finished PCBs.

Exact cable terminals, sockets/contact lengths, magnetic retention, printed fits, keycap insertion, screw access with real tools, RF, charging and consumption still need verification. [Revision review](revI-review.md).

The September 23 identity migration preserves the original geometry. Native metadata and current filenames use Flan36; previous generation receipts keep their original source hashes. [Rename checks](../validation/rebrand-file-map.json) bind the previous snapshot to the current files.

## Color and frame update checks

The additive [frame installer](frames-extra.md) preserves manually edited source geometry. The color and print checks run after rebuilding the viewer:

```sh
node viewer/keycolors-check.cjs
node viewer/capture-customization.cjs
node viewer/customize-check.cjs
python tools/check_print_kit.py
python3 tools/freecad/run_macos.py tools/freecad/check_keycolors.py
python3 tools/check_customization_delivery.py
```

`build/keycolors/` and `build/themes-print/` are ignored, reproducible test outputs: JSON/GLB downloads, palette collections, print ZIPs, screenshots and a native save/reopen copy. Native frame comparisons use `check_frame_extensions.py --source ORIGINAL.FCStd --candidate CANDIDATE.FCStd --report REPORT.json`; this reads both files without replacing either. The [mount study](slim-mount-study.md) produces separately named experimental geometry and a measured report under `build/`.

The current [delivery check](../validation/revI-customization.json) binds colors, native geometry, print exports and the measured study. Its [Label-only identity receipt](../validation/revI-document-label.json) preserves the original geometry checks' hashes: FreeCAD's temporary `saveAs` name was corrected without changing any geometry or GUI member. The installer now preserves that label automatically. These digital checks do not qualify the keyboard for manufacturing.

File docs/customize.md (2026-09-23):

# Choose your keycaps and frames

Open the **[3D configurator](https://eduarbo.github.io/flan36/)**. No account or paid software is required.

## Keycap colors

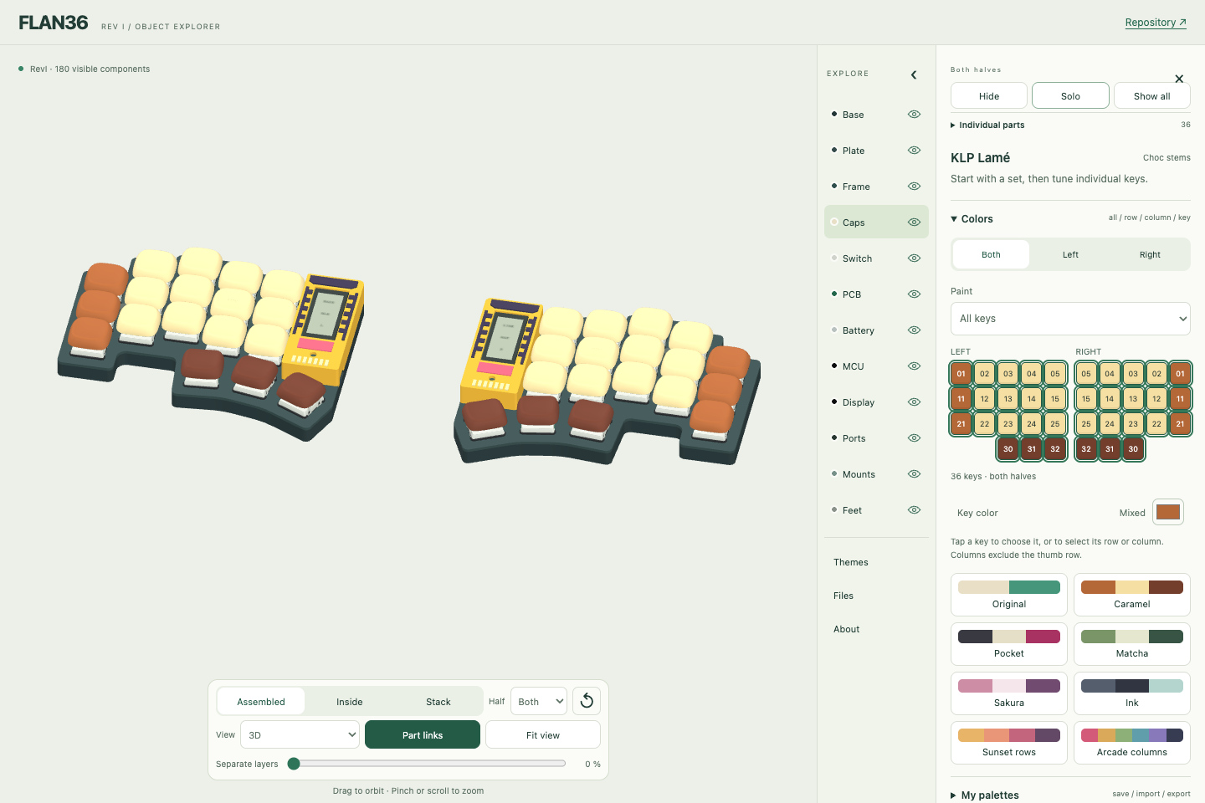
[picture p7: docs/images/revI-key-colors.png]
Keycap color editor using the actual KLP meshes


Open **Caps → Colors**. Choose **Both / Left / Right**, then **All keys, Row, Column or Individual key**. Tap the key map to select a key or its group; pick a color to apply it immediately. Finger columns exclude thumbs. The **Thumbs** row colors all three thumb keys on the selected halves.

Eight keycap palettes provide starting points, including row and column patterns. They change key colors only. **My palettes** saves the exact colors of all 36 keys, with JSON import/export for sharing or another device. **Themes** applies a coordinated palette to the case, frame and keys. Changing keycap shape or rotation preserves its color.

Configuration JSON, GLB and the FreeCAD import/export macro retain individual key colors. STL has no color data: assign filament per key or paint in the slicer. The case/frame print kit does not include keycap toolpaths; use the unchanged KLP source meshes for those.

## KLP Lamé

Open **Caps** in the directory, then click a preset preview to apply a complete set. Open **Edit keys** to choose a row, all thumbs or one key. Select a variant and rotation, then **Apply to these keys**. Each change checks the complete configuration, including neighboring keycaps and the frame.

| Choc-stem family | Files | Qualified reference positions |
|---|---:|---|
| Choc-size 1U | 7 | All 36 keys, at 0° or 180° |
| Choc-size 1U, 90deg stems | 7 | Thumbs only, at 90° or 270° |
| MX-size 1U, standard stems | 7 | Thumbs only, at 0° or 180° |
| MX-size 1U, 90deg stems | 7 | Thumbs only, at 90° or 270° |
| Choc-size and MX-size 1.5U | 10 | None qualified with the reference neighbors |

The seven 1U profiles are **Normal, Normal Homing, Normal Tilted, Saddle, Saddle Homing, Saddle Tilted and Thumb**. Each size also includes 1.5U Normal, Saddle H/V and Thumb H/V.

**MX size describes the keycap body, not its stem.** Every file in this catalog has Choc stems. MX-stem files are incompatible with the selected switches and are excluded. A `90deg` file rotates the stems inside the cap; the whole cap must then rotate 90° or 270° to match the unchanged switch. Actual stem geometry, rather than the H/V filename alone, determines allowed orientation.

The full [catalog](../keycaps/catalog.json) includes all 38 files and their source hashes. Unsupported 1.5U files remain available for study, but the configurator does not enable them. Failed conservative qualification is not proof that every possible physical arrangement is impossible.

The check uses unchanged STL convex envelopes with **at least 0.20 mm XY clearance**. Clear envelopes remain separate throughout independent vertical motion. A **3.5 mm travel study** keeps the complete cap mesh at least 0.6 mm above the plate, using an illustrative common stem-tip height of 11.7 mm. This does **not** prove real seating, switch travel or printed stem fit. Tilted caps are seated from their stem tips, rather than given the same arbitrary mesh origin as flat caps.

For the lowest profile, start with the flat variants. At the common nominal seating datum, Choc-size Normal/Thumb tops reach **17.87 mm**, Saddle **17.78 mm**, and Tilted variants **21.34 mm**, before feet. Tilted caps therefore add about **3.5 mm** locally; their comfort and final seated height need a physical trial.

Presets: **Original**, **Sculpted Normal** and **Sculpted Saddle**. The sculpted presets use tilted upper/lower rows in opposite orientations; they are starting points for comfort trials, not an ergonomic prescription.

## Print a themed display frame

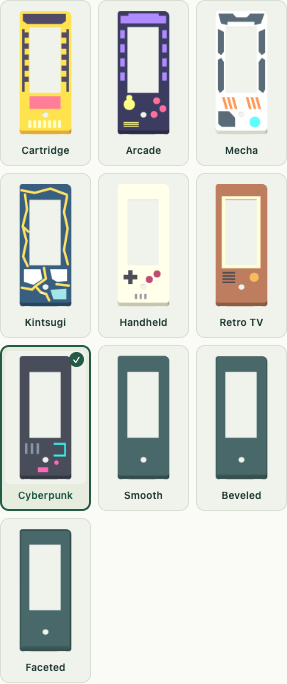
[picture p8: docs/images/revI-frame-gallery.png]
Ten actual native frame previews


Open **Frame** in the directory, then choose Both halves, Left or Right, then click a theme thumbnail to apply it immediately. Each preview shows that actual mesh with its original palette. A click applies the design and its colors together. **Body** changes the shell color without changing the accent colors; **Restore design colors** restores the palette for the selected half or halves. You can also select the frame directly on the model to open its sidebar options for that half.

| Theme | Body | Contrasting raised details |
|---|---|---|
| **Handheld** | Warm cream | Charcoal D-pad, berry buttons, gray speaker bars |
| **Retro TV** | Walnut brown | Ivory CRT bezel, brass tuning knob, charcoal speaker grille |
| **Cyberpunk** | Graphite | Steel vents, cyan traces, magenta panel and node |
| **Cartridge** | Saffron | Violet grip ribs, gold contacts, coral label |
| **Arcade** | Midnight blue | Violet marquee, pink buttons, yellow joystick |
| **Mecha** | Ivory | Slate armor, orange hazards, cyan reactor |
| **Kintsugi** | Blue glaze | Porcelain shards and gold repair lines |
| Plain options | Your chosen body color | Smooth, Beveled and Faceted |

The controls are decorative. No logos, extra switches or LEDs are required. All ten styles use the same window, cavity, three magnetic stations and independent display support. Each exports as one closed solid per half. Relief stays within the 24 mm bay, without antennas or side wings.

| Interface | Nominal dimension |
|---|---:|
| Frame envelope | 24 × 56 mm; R2.4 at the shared case corner beside USB, R1.2 at the other corners |
| Plain top / themed relief top | 16.6 / 17.2 mm above the base datum |
| Structural roof / side wall | 1.2 / 1.2 mm |
| Glass margin, each side | 0.4 mm |
| Magnet / steel pin | Ø2 × 3 / Ø2 × 4 mm |
| Magnetic gap / guide radial clearance | 0.9 / 0.2 mm nominal |
| Relief height | 0.6 mm; fused into the roof |

The frame ends before the thumb key; the **low case and plate continue along the straight flank**. The power switch is recessed inside the side access cut. Key positions remain fixed.

### Make your own

Open the native source and expand **Construction**. Duplicate a supplied theme, then edit the `Theme_*` boxes/cylinders or the frame section sketches. Preserve the cavity, mounting bosses, screen window and service cuts. The case outline is a native sketch with **21 intentional corners with locally bounded tangent arcs and straight faces parallel to each thumb**; mesh tessellation does not add design corners. Remove only the Block constraints you intend to edit.

Keep decorations within the common envelope. Preserve the magnetic stations at left **(113, 52.8)**, **(133, 52.8)** and **(122.8, 64.7)**, the hidden structural screw reliefs at **(114.5, 65.5)** and **(130.6, 66.5)**, the reset tool opening at **(123, 59.5)**, and the glass window. Right-half coordinates mirror across X=80 mm. Relief adds material above the roof; cutting through it changes the validated wall thickness.

Use the viewer’s JSON for the ten supplied shapes. To share a new shape, save your FCStd, export STEP/STL, rebuild the viewer and repeat collision checks; JSON alone cannot carry arbitrary geometry.

### First print

Start with **one frame in PLA Basic** as a fit sample. Use 0.16 mm layers as a starting point so the 0.6 mm relief is visible; inspect it in the slicer. Face-up protects the visible details but the roof/inside may need supports. PETG HF is an alternative to compare after the fit sample; ABS requires shrinkage compensation from an actual print. No material-specific tolerance has been qualified yet.

For contrasting accents, paint raised faces in the slicer if your printer setup supports multiple colors, or paint them after printing. The table above is the color map. STL contains geometry only; it does not retain these colors. GLB preserves the visual materials, and importing the JSON with the current FreeCAD macro applies matching face colors. No multicolor printer accessory is assumed. These are one-piece frames; separate colored inserts and ready-to-print multicolor toolpaths are not included.

Print capture, magnet temperature, holding force and extraction still require a physical trial. Use the [small coupons and assembly sequence](build.md#magnetic-frame-and-service) first. The reset opening takes a tool. A nominal 12 × 5 mm USB plug and straight insertion corridor clear each theme; cable housings vary.

The [new frame recipes](frames-extra.md) are editable native features. The [slim support study](slim-mount-study.md) separates fewer loose parts from lower stack height.

## Save a configuration for FreeCAD

1. In the viewer, choose caps, rotations, frame styles and colors. In **Battery**, select Adafruit 1570 or 301230.
2. Open **Files** and click **Save configuration** to download `Flan36-config.json`.
3. Download and unzip the full repository. Open `mechanical/revI/Flan36.FCStd` in FreeCAD.
4. Use **Macro → Macros → Execute** on `tools/freecad/Configure.FCMacro`. Keep the macro beside its companion files in the repository.
5. Choose **Import viewer configuration**, select the JSON and use **Save As**.

The macro changes the actual keycap meshes, placements, frame links and battery envelope links, and applies the theme’s face colors. The JSON retains your body-color override; accent colors come from the shared [theme definitions](../design/frame-finishes.json). After changing the frame height, import the configuration again to reapply face colors against the current roof height. It validates the JSON before applying it and preserves other mechanical parameters. Its export action writes the same configuration format back to the viewer. Invalid choices are rejected without replacing the current configuration.

The JSON stores selections, not arbitrary FreeCAD shape edits. If you change wall geometry, PCB placement or other dimensions, keep the edited FCStd and recheck the assembly; loading JSON alone does not transfer those changes. [Editing guide](freecad.md).

KLP Lamé by braindefender, CC-BY-SA-4.0, pinned to commit `4a67a824232d3054c61599ea047c56a340faaba2`. Meshes are unchanged. [Upstream files and guidance](https://github.com/braindefender/KLP-Lame-Keycaps).

Configurations are tagged revision I. Older revision H JSON is not silently converted: reselect its options in the current viewer and save a new configuration. Manual FCStd edits stay in their original file.

## Case geometry

Choose **Base → Solid / Color rim / Terrace** in the explorer. Each half has its own `cases` entry, for example `"left": {"style": "rim", "cover": false}`. `cover: false` omits the printed display cover and its steel targets; it retains the display and supports. JSON import validates both halves before changing anything. Older configurations without `cases` use Solid with covers. [Geometry, files and printing](cases.md).

## Coordinated themes and print kits

See [Make it yours](themes-printing.md) for sixteen palettes, linked frame/rim colors, individual color regions, device saving and the selected-parts print kit.

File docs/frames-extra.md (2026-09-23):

# Creative frames

Cartridge, Arcade, Mecha and Kintsugi add printable relief to the Smooth frame.
Choose a thumbnail in the [viewer](https://eduarbo.github.io/flan36/), customize
its colors and export your configuration or print kit. See [customization](customize.md)
for the complete workflow.

| Frame | Design | Default palette |
| --- | --- | --- |
| Cartridge | Grip ribs, label plate and contact fingers | Saffron, violet, pale gold, coral |
| Arcade | Stepped marquee, side lights, joystick and three buttons | Midnight, violet, pink, yellow |
| Mecha | Angular armor, hazard bars and reactor | Ivory, slate, orange, cyan |
| Kintsugi | Porcelain islands and raised repair lines | Blue, porcelain, gold, celadon |

The controls are decorative. Each design is one fused solid, with color regions
on its actual faces. STL carries geometry only; assign materials or paint regions
in your slicer. See [themes and printing](themes-printing.md).

## Fit and printing

- Relief rises at most **0.6 mm** above the Smooth roof without widening its footprint.
- The screen opening, service cutouts, underside and mounting interfaces are inherited
  from Smooth. These designs do not lower the electronics stack or change the mounts.
- Some details are **0.45 mm** wide. Inspect the sliced toolpaths before printing.
- Digital validation checks connected solids, closed meshes, preserved interfaces
  and service clearances. **Printed fit remains unqualified; these are prototypes.**

## Edit in FreeCAD

Open [Flan36.FCStd](../mechanical/revI/Flan36.FCStd) and expand `L_ExtraFrames` or
`R_ExtraFrames`. The boxes, cylinders, sketches and Boolean features are native
editable objects; the saved file needs no custom Python classes. Save a copy before
editing. Relief heights follow `Parameters.FrameTop`.

For repeatable changes, edit the [shared recipes](../design/frame-extensions.json)
and regenerate a separate candidate. From the repository root on macOS with
FreeCAD installed:

```sh
frame_dir="$(mktemp -d /tmp/flan36-frames.XXXXXX)"
python3 tools/freecad/run_macos.py tools/freecad/install_extra_frames.py \
  --source mechanical/revI/Flan36.FCStd \
  --output "$frame_dir/Flan36-extra.FCStd" \
  --report "$frame_dir/frame-report.json"
```

The installer refreshes only its four extension designs per half, preserving the
original geometry, appearance and active configuration. It saves and reopens the
candidate before accepting it, using offscreen GUI support to retain face colors.
Review the report and candidate before adopting changes; the source file above is
left untouched. Regenerating recipes replaces edits to extension-owned features.

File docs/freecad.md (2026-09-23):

# Design with free tools

**KiCad for the circuit. FreeCAD for the case. StepUp to bring them together.**

## Start here

1. Download the [complete repository ZIP](https://github.com/eduarbo/flan36/archive/refs/heads/main.zip) and unzip it.
2. Install [FreeCAD](https://www.freecad.org/downloads.php) and [KiCad](https://www.kicad.org/download/).
3. In FreeCAD’s Addon Manager, install [KiCad StepUp](https://github.com/easyw/kicadStepUpMod).
4. Open [`mechanical/revI/Flan36.FCStd`](../mechanical/revI/Flan36.FCStd). Importing STEP instead loses the editable history.

The source opens and recomputes without StepUp, CadQuery or custom Python proxies. StepUp is only needed for exchange with KiCad. KLP keycaps and the 36 linked Choc v1 instances are meshes. The nano, display and standard switches have separate nominal visual parts; some connectors remain dimensional reserves. [Component sources and limits](../components/README.md).

## Navigate the assembly

The tree contains **Parameters**, **Left** and **Right**. Select a part and press **Space** to hide or show it. Expand **Construction** for sketches and operations. Each half has an **ActiveFrame** link to one of ten cover bodies; an **ActiveBattery** link selects Adafruit 1570 or 301230. Hidden alternatives do not represent extra installed parts.

For keycaps, frame styles and colors, use the [configurator and companion macro](customize.md#save-a-configuration-for-freecad). Keep a personal copy with **File → Save As** before editing dimensions.

## Three editing examples

### 1. Change the cover

In **Parameters**, change `FrameTop` from **16.6 to 17.2 mm** and recompute. Plain covers extend to the new top height; themed relief stays 0.6 mm above it. Save, close and reopen to confirm the change, then restore 16.6 mm.

`FrameRoof` controls roof thickness and `WindowMargin` the clearance around the glass. Start from 1.2 and 0.4 mm respectively. The supplied dimensions were checked as a nominal assembly; arbitrary edits are not automatically cleared for fit or printing. For new frame shapes, edit the outline sketch (or loft sections for Beveled/Faceted) while preserving the shared cavity and mounts.

### 2. Move the display

Hide the active frame and keycaps. Change `DisplayShiftY` from **2.4 to 3.4 mm**. The complete display, sled and window move together; do not drag the glass alone. Restore 2.4 mm before comparison with the published PCB.

`MCUShiftY`, `MCUBottom`, `BatteryShiftY`, `BatteryBottom` and plate dimensions provide other study controls. **Moving a part in FreeCAD does not update KiCad footprints or traces.**

### 3. Inspect the PCB with StepUp

Open `hardware/revI/flan36-left.kicad_pro` in KiCad. RevI matches the chosen contour and adds battery/magnet clearances. H1/H3/H4/H5, J1 and SW1 move; all key transforms, footprint identities and nets are preserved. Switches are locked to preserve the layout; both boards remain unrouted.

The project-relative STEP files show the current nominal component models in KiCad's 3D Viewer. Their source, colors and placement are checked without changing footprints. Connector reserves and unqualified fit remain identified in the [component guide](../components/README.md).

In StepUp, enable **Virtual models**, keep **Grid Origin**, include holes from **0 mm**, and apply no outline tolerance. The boards’ grid origin is explicitly **(10, 10) mm**. In a new FreeCAD document, use **Load KiCad PCB**.

Work on a copy for **Pull Sketch from PCB** / **Push Sketch to PCB**. The historical revF exchange example moves only the battery opening’s rear edge from KiCad **Y 46.95 to 47.45 mm**, along with its two connecting segments. Reopen the copy in KiCad and verify that switch centers, angles, pads, connectivity and the outer contour are unchanged. This demonstrates exchange, not an approved battery-opening improvement.

The native assembly uses **X = KiCad X, Y = −KiCad Y**, with PCB top at **Z 5.4 mm**. To overlay a StepUp import for inspection, move its complete group by **X +10, Y −10, Z +5.4 mm**. Preserve the original import for pushing back. The right half’s **161 mm X separation** in the assembly is visual only and must never be written to its PCB.

## Export the right file

| Format | Use |
|---|---|
| FCStd | Editable mechanical source and assembly history |
| KiCad project / schematic / PCB | Editable circuit, layout and routing |
| STEP | Solid geometry for other CAD tools; no full feature history or KLP meshes |
| STL | Individual part for slicing; check orientation and fit first |
| GLB from the viewer | Visual assembly with selected keycaps and frames, in meters |
| Configuration JSON | Keycap variants, rotations and individual colors; case/frame colors and battery profile; not manual shape edits |

Select a part and use **File → Export**. Store exports outside the reference folders and keep the edited FCStd. The generation scripts rebuild the reference from scratch and overwrite its files; do not run them over manual work.

The project remains a digital prototype. Both boards have **zero geometric DRC violations and 104 unconnected items each**; measured minimum pad-to-outline clearance is about **0.524 mm**. Final cable/connector geometry, printed fit and retention, RF and power measurements remain open. [CAD reproduction and validation](cad.md).

## Interchangeable cases

[Solid, Color rim and Terrace](cases.md) are native source bodies. The configuration macro changes `ActiveTray` and `ActivePlate` per half. `DisplayCoverInstalled` records whether to include the printed frame and its steel targets; JSON import applies the corresponding visibility, and export honors this property. Save a custom FCStd copy to retain your choices. The property represents installation, independently from temporary eye visibility.

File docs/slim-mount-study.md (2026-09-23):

# Slim support study

**The reference stack stays at 16.6 mm.** A 15.6 mm roof clears the modeled
components, but remains experimental: all three tested recipes have a display
removal conflict with the battery leads. None is qualified for manufacturing.

The completed study covers both halves, all **10 frames** and both battery
profiles: **Adafruit 1570** and **301230**. It also evaluates support consolidation
for Solid, Color rim and Terrace.

[Download the STEP/STL study pack](../mechanical/studies/slim-mounts.zip) ·
[Measured results](../validation/revI-slim-mounts.json)

## Height comparison

Dimensions start at the case bottom and exclude feet.

| Recipe | Display bottom | Plain roof | Decorated top | Static result |
| --- | ---: | ---: | ---: | --- |
| Reference | 14.2 mm | 16.6 mm | 17.2 mm | Clear in the modeled checks; retained |
| Lower candidate | 12.4 mm | 15.6 mm | 16.2 mm | Clear in the modeled checks; experimental |
| Rejected limit | 12.4 mm | 14.8 mm | 15.4 mm | Roof intersects the JST connector |

The selected KLP Lamé keycaps keep the complete assembly at **17.87 mm**
in every recipe. Lowering the electronics cover therefore changes
its profile without reducing this configuration's maximum height.

At 15.6 mm, the modeled JST-to-roof clearance is **0.5 mm**, and the shortest
MCU-to-display distance is **0.82 mm**. These are mechanical distances, not proof
of pin engagement or electrical continuity. At 14.8 mm, JST roof clearance becomes
**−0.3 mm** in every frame; the same obstruction also affects the first frame-lift
samples. The ZIP includes this rejected recipe for comparison, not as a print
recommendation.

## Fewer loose supports

| Study option | Result across both halves | Loose parts removed | Height change |
| --- | --- | ---: | ---: |
| Plate with its three washers fused in | All six case/half variants form one connected solid and preserve the combined envelope and PCB seats | 6 | 0 mm |
| Base with its battery saddle fused in | All six variants form one connected solid and preserve the combined envelope and datums | 2 more | 0 mm |

These parts are exported separately under `support-consolidation/` in the ZIP.
The fused saddle is optional because it loses independent replacement. Print
orientation, insulation, strength and retention still need physical tests.
The battery cage, MCU riser, display sled, magnets and independent fasteners remain;
this study does not qualify removing their support or retention functions.

## Service conflict to resolve

Lifting the display and sled together crosses modeled `battery-lead-0` and
`battery-lead-1` at **0.5–2 mm** of travel. Each recipe records **28 collision
samples** across both halves and batteries. This also affects the reference stack,
so the overall service checks **do not pass**.

The other recorded USB, driver, PCB-lift, cell-motion and insert/cage-capture checks
show no failures. Reference and 15.6 mm frame-lift samples are clear; the 14.8 mm
recipe additionally hits the JST connector. These are sampled checks, not proof
of a continuous extraction path or real connector disengagement.

The next mechanical change is to reroute or release the battery leads before
lifting the display, then recheck the complete extraction sequence and real lead
ends. The lower display also needs measured mating datums and pin engagement.
Physical fit, tolerances, wire forces, magnetic hold and print durability remain
unqualified.

## Reproduce

From the repository root with the documented FreeCAD macOS runtime:

```sh
FLAN36_STUDY_SOURCE="$PWD/mechanical/revI/Flan36.FCStd" \
FLAN36_STUDY_OUT="$PWD/build/slim-mount-recheck" \
python3 tools/freecad/run_macos.py tools/freecad/study_slim_mounts.py
```

Choose a new or empty output directory. The headless study leaves the native file
untouched and writes STEP/STL parts, `README.md`, measurements and hashes to the
ignored `build/` directory. The [checker](../tools/freecad/study_slim_mounts.py)
reports rejected geometry as findings; finishing a run does not mean its recipes
passed. To run a single recipe with the same checks, set `FLAN36_STUDY_RECIPE` to
`reference-16p6`, `nominal-15p6` or `limit-14p8` and use
[`study_slim_candidate.py`](../tools/freecad/study_slim_candidate.py) as the target.

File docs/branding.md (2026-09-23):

# Flan36 Outline

The selected logo: an open flan contour with a solid lowercase **flan36** wordmark.

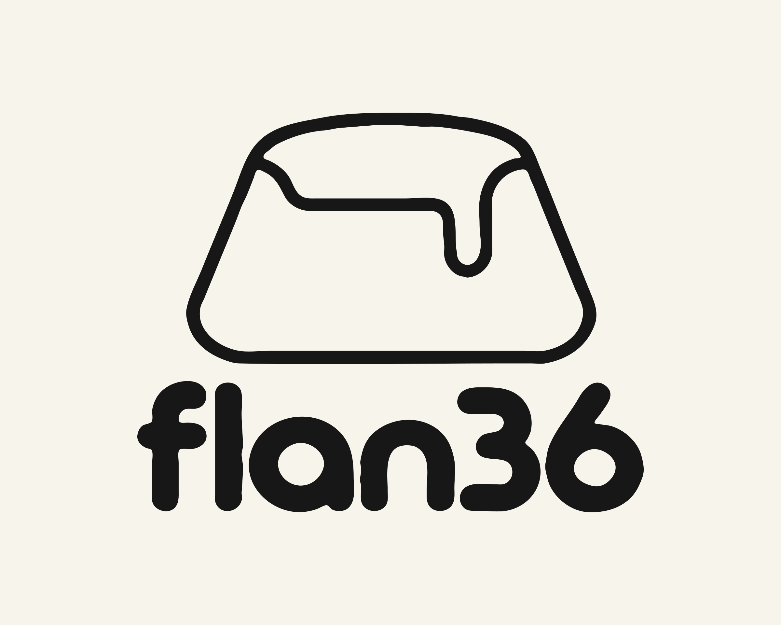
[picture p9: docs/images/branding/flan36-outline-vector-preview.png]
Selected Flan36 Outline logo


**[View logo](https://eduarbo.github.io/flan36/branding.html)** · **[Download SVG kit](https://eduarbo.github.io/flan36/branding/outline/flan36-outline-svg-kit.zip)** · [Import guide](branding/outline/README.md)

The kit contains one editable master and three exports of the same logo: complete mark, symbol and lettering. All are closed paths with no font dependency. FreeCAD import and trial extrusion are checked; PCB placement and case relief remain pending.

The project's canonical repository is **[eduarbo/flan36](https://github.com/eduarbo/flan36)**. Current CAD, PCB files and new configuration exports use Flan36. Earlier configuration files remain importable. Previous design studies and original generation records remain historical provenance, outside this gallery.

[Credits](../ATTRIBUTION.md) · [Current asset record](../design/branding-outline-vectors.json)

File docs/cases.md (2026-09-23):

# Pick a case

[Open the 3D explorer](https://eduarbo.github.io/flan36/) → **Base** or **Plate** → choose a thumbnail. Apply a design to both halves or mix them.

| Solid | Color rim | Terrace |
|---|---|---|
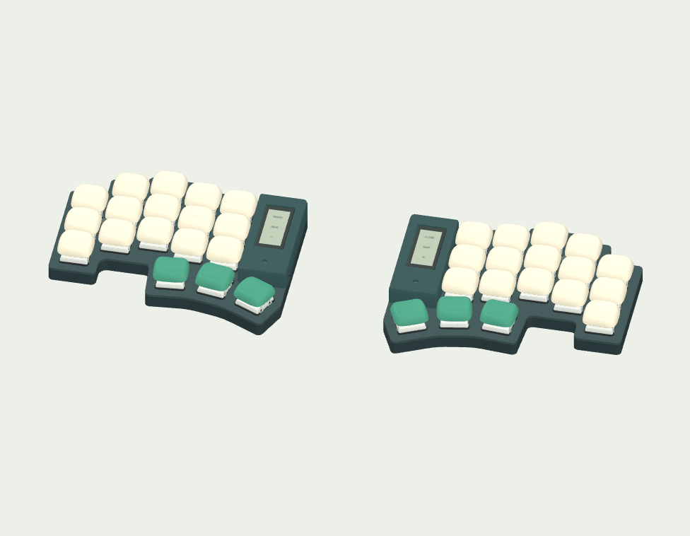
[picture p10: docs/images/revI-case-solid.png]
Solid
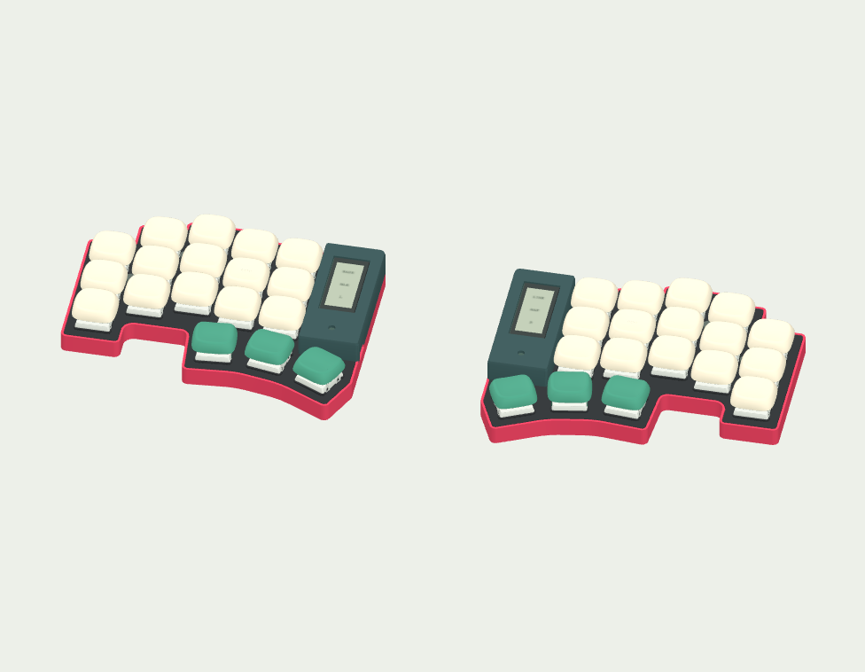
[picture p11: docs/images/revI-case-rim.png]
Color rim
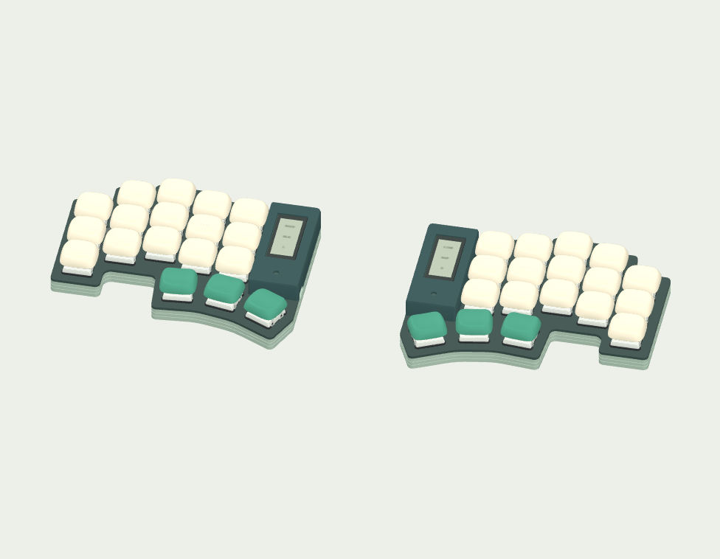
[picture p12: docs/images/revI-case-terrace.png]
Terrace
|  |  |  |

| Design | Geometry | Suggested finish |
|---|---|---|
| **Solid** | Full plate over a continuous sidewall | Deep teal |
| **Color rim** | 0.9 mm wide rim flush with the plate, 1.1 mm plate inset, 0.2 mm joint | Red base + black plate |
| **Terrace** | Two 0.25 mm deep, 0.6 mm high recessed side bands | Sage base + dark plate |

All three follow the same Piantor key positions. Straight thumb faces stay parallel to their keys; tangent arcs soften their joins. Finger corners use up to R2.4, reduced locally at short steps. The pinky backbone remains 90°. No screw adds an outward bulge, and the thumb flank stays within the display-panel edge.

The shared outline is **116.75 × 94.57 mm per half**. Its 4.75 mm straight-face allowance protects the existing pads on both boards. The Color rim changes the visible plate edge without reducing that PCB budget. Terrace leaves at least 1.05 mm nominal sidewall away from intentional service openings; the 1.4 mm floor stays unchanged.

## Open or covered

Uncheck **Printed display cover** to expose the current stack. The display, controller, battery and structural supports remain; the printed cover and its three steel targets are omitted. Choose any display frame to reinstall it. This is the wireless nice!nano/nice!view stack, not the Raspberry Pi Pico arrangement in the inspiration photo.

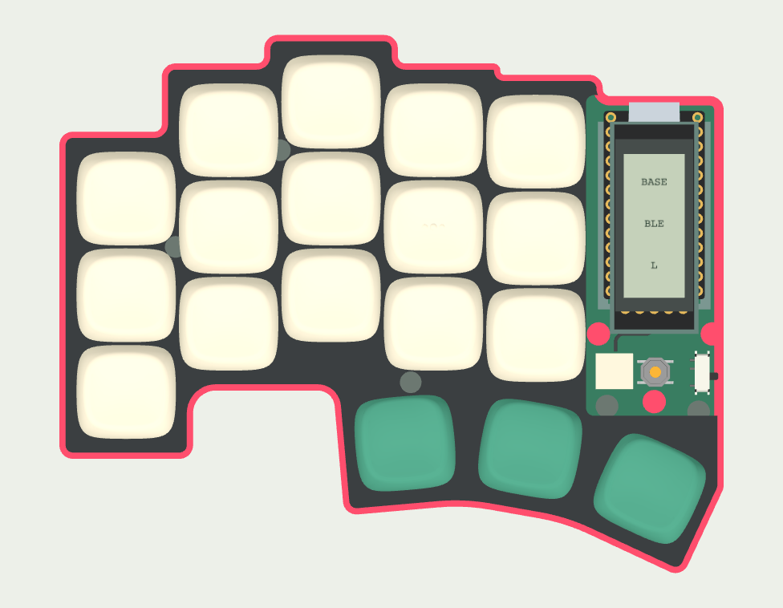
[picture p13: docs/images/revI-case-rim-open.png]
Color rim with the display stack exposed


**Eye / Solo** only change visibility. **Printed display cover** changes the saved assembly. Both choices are reversible, but only the assembly choice affects exported GLB and FreeCAD configuration.

## Edit and print

Download [Flan36.FCStd](../mechanical/revI/Flan36.FCStd) and use the [FreeCAD guide](freecad.md). `ActiveTray` and `ActivePlate` link to native `Case_solid`, `Case_rim` or `Case_terrace` bodies. Edit their source sketches and boolean operations under **Construction**. No custom Python proxy is needed to reopen the document.

[All case parts](../mechanical/revI) use `left-case-{solid,rim,terrace}-{base,plate}.{step,stl}` and matching `right-` names. Exported parts retain assembly coordinates. The viewer saves per-half case and cover choices in JSON; import that JSON with the configuration macro. Older JSON defaults to Solid with covers installed. The assembled GLB includes the selected meshes, including when view layers are hidden.

Print the base and plate separately for contrasting colors; a multicolor printer is optional. Use the existing [fit coupons and rebuilding commands](cad.md) before a full shell. The raised rim and recessed bands are real geometry. Nominal CAD checks do not qualify their printed strength, snap or thread fit, magnetic holding force or actual electronics clearances.

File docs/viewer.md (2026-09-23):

# Explore the assembly

**[Open the 3D viewer →](https://eduarbo.github.io/flan36/)**

The component directory stays visible while you inspect or customize the keyboard. Its 12 entries include **Frame**, **Caps**, **PCB**, **Battery** and **MCU**. Open an entry for its controls or information; use its eye to show or hide that layer. Open **Individual parts** within a selected entry to toggle a single piece. **Hide / Show** acts on the selection, **Solo** hides everything else, and **Show all** restores every piece and both halves. Each individual piece also has its own Solo button. **Files** and **About** remain beside the directory. View controls have a fixed bar below the model, independent of the details panel.

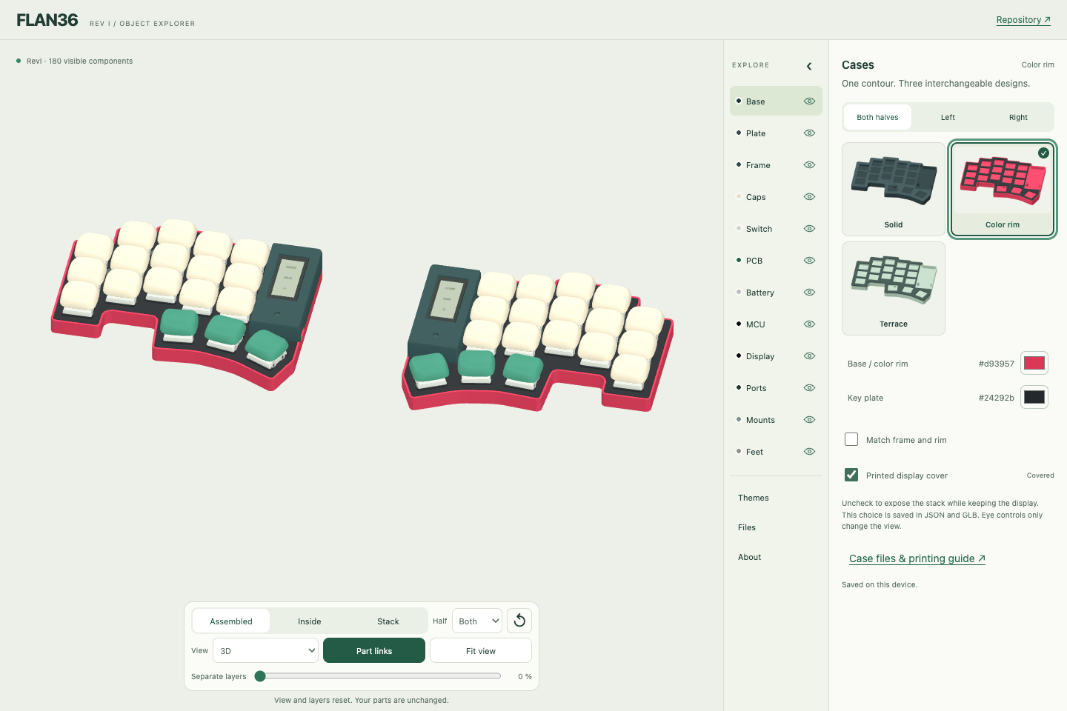
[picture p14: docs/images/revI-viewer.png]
A component connected directly to its sidebar entry


## Follow a component

Hover anywhere across a directory row, including its eye, or focus an entry to highlight its visible parts. Click or tap to keep the selection. A selected frame keeps its actual colors; its surface highlight appears only while hovering or focusing the component entry. You can also select a part directly in 3D. A fine line connects the active visible part to its exact directory entry; there are no floating tags. Hover uses a temporary translucent X-ray highlight, so parts remain identifiable behind the case or display. It also previews deliberately hidden pieces without changing their visibility. When no visible surface is available, the hover line points into that component. Leaving hover restores the assembly; selecting an occluded part does not keep the X-ray active.

**Frame** opens six actual-mesh previews. Choose a half, then click a thumbnail to apply the shape immediately. A thumbnail applies that design and its original multicolor palette. **Body** overrides the shell color while preserving the theme’s accents; **Restore design colors** resets it. The front-facing previews show the actual raised details. **Caps** opens KLP presets and individual key editing. **Battery** switches between Adafruit 1570 and 301230 in the shared cradle. Other entries explain the component and its current limitations.

The arrow beside the directory collapses only the details. Component names and section controls stay visible, including while the details scroll. The mobile directory uses a compact grid; all entries stay visible while the detail area scrolls and the model stays on screen.

Clear a selection with **×** or **Escape**. **Part links** toggles the connecting line and explains when selection or visibility is needed. During a camera gesture, the line pauses; it reconnects after the gesture settles. Expensive surface searches no longer run during every camera update.

## Move and inspect

Drag to orbit, scroll or pinch to zoom, and use two fingers to pan. The fixed **View** selector includes 3D, Top, Front, Bottom and side views. **Fit view** centers and fits visible parts without changing the angle; it reports when nothing is visible. **↺** resets the view and layers while keeping your chosen parts.

The same always-visible bar contains **Assembled**, **Inside**, **Stack**, half selection and **Separate layers**. Exploded spacing is a viewing aid; it does not alter saved geometry. Dragging or using two fingers does not select components.

## Keep your choices

Open **Files** for Save configuration, Load JSON, Restore default parts, GLB and offline downloads. JSON transfers selections to another browser or [FreeCAD](customize.md#save-a-configuration-for-freecad). Restoring defaults changes parts; resetting the view does not.

**Download offline HTML** includes geometry, previews, code and licenses. It needs no network requests after download. The file remains about 33 MiB because it contains the original supported meshes; first-load time depends on the device and connection.

**Download assembled GLB** exports all installed parts in their assembled positions, with the selected keycaps, frames, colors and battery profiles. Hidden layers, exploded offsets, lines and highlights do not alter the exported assembly. GLB uses meters and retains attribution; use FreeCAD/STEP for solid editing.

This remains a nominal CAD study. See [dimensions and limitations](cad.md), [customization rules](customize.md) and [parts](parts.md). Browser checks distinguish desktop and emulated touch viewports from physical-phone and hardware acceptance.

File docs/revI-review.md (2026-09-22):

# Revision I review

**Chosen Contour outline, magnetic frames and two battery profiles. Digital prototype only.**

The source reference requested a stepped finger outline, rectangular pinky foot, shallow recess and continuous thumb fan. The actual CAD and PCB now use that contour while preserving all 36 Piantor key transforms. Internal fasteners and magnetic stations add no perimeter lobes.

Two independent read-only reviews covered geometry/serviceability and failure modes before the magnetic design was adopted. The recorded source snapshots stayed unchanged during their review. [Decision record](../validation/revI-design-review.json).

## Key-aligned local curves and case variants

The latest contour replaces the spanning thumb spline with three key-parallel straight faces and local tangent rounds. Finger corners use R2.4 where space permits, smaller radii at short steps, and wider blends at the thumb joins/recess. The pinky backbone stays 90°. The LCD flank remains at left X=135 / right X=25. Both halves derive from one reflected contour.

Solid, Color rim and Terrace share that perimeter. The Color rim has a raised border 0.9 mm wide and inset plate; Terrace cuts two shallow exterior bands. See [case designs](cases.md). No key, mount, magnet or battery position changes. The straight-face allowance stays 4.75 mm: a 4 mm study failed against right-hand pads and was rejected before native generation. Actual copper clearance remains at least 0.5 mm.

The former broad-cubic revision remains in Git and in `revI-local-curves-baseline.json`. New acceptance checks target local native arcs, key-aligned faces, both actual PCB pad sets, all case/frame combinations and selected-mesh JSON/GLB/FreeCAD correspondence. Earlier review receipts below describe their dated snapshots, not the current corner geometry.

## Uniform rim correction — prior revision

The earlier contour was mirrored, but its exposed margins varied from **2.53 to 5.42 mm**. Hand-entered vertices and a containment-only test allowed that discrepancy. That revision derived its faces from the switch openings at **4.75 mm**, with offset thumb edges and H1 relocated to **(38.7, 37.5)** inside the first two columns. Its post is R2.1; the M2 screw is unchanged.

Why 4.75? The outer thumb hot-swap pad reaches 9.575 mm from its center. Preserving the 1.65 mm case-to-PCB offset and 0.5 mm copper rule requires at least **4.725 mm** of visible rim. A 4 mm draft cut that pad. Its envelope was 119.30 × 95.10 mm; its area differs by only 0.0072% from the previous contour. The electronics bay stays 24 mm.

The left contour alone generates both halves. Measured straight faces, local tangent blends, internal bridges and the bay joint have separate definitions. The test rejects the old outline and reads the actual native plate solids; it does not treat every interior key as peripheral. [Rim measurements](../validation/revI-rim-solids.json) · [Fastener/keycap travel](../validation/revI-fasteners.json) · [Decision and correction record](../validation/revI-rim-review.json).

The current diagram above supersedes that geometry; the previous receipt and regression fixture preserve its measurements.

## Earlier corrections during verification

- H3 was outside the new recess: it moved into existing material. H4/H5 moved below the electronics, with short screws and underside head reliefs.
- The earlier wide battery opening violated the copper-edge rule: the saddle now stays below the board, with only the cell/cage crossing a 12.5 mm opening.
- An initial magnet position cut a K25 pad: actual pad polygons exposed the conflict. Stations moved south; J1 and SW1 moved to preserve clearance. The power switch also moved inward. No key moved.
- The battery cage touched the controller support: the rear support bridge moved clear of the cage.

Both KiCad studies have **0 geometric violations and 104 unconnected items per half**. This is not a routed-board DRC pass or fabrication release. The original 0.5 mm copper-edge rule remains in force; measured minimum pad clearance is approximately 0.524 mm.

- A frame could fit at rest yet catch the MCU while lifting. Its internal relief now opens to the lower rim; sampled extraction checks cover all six styles.
- A FreeCAD link dropped a battery box's placement. Each battery variant now has a native compound wrapper, and independent bounds checks verify the active link, exported mesh and configuration swap.

## Physical work still open

Magnetic holding force, north-edge peel, closed-pocket print capture, actual magnet temperature, printed M2 threads and cycling need coupons. Both battery fits use supplier nominal dimensions; wrapping, insulation, protection electronics, cable terminals and connector polarity must be checked on delivered parts. Socket heights, hot-swap assembly, firmware, charging, BLE and consumption remain unverified.

The wire study reserves two 105 mm paths with 1.5 mm bends and 0.6 mm insulation diameter. It is not a terminal-complete harness. Sampled frame lifts are nominal collision checks, not a continuous tolerance analysis or a physical extraction test.

[Mechanical](../validation/revI-mechanical.json) · [Outline and clearances](../validation/revI-outline.json) · [Electrical](../validation/revI-electrical.json) · [Service and coupons](../validation/revI-service.json) · [Build sequence](build.md).

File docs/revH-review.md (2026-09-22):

# Revision H: continuous edge and themed frames

The red-line reference called for one continuous inner edge from the display to the outer thumb. RevG still had a notch and a wide thumb-plate wing. Its three taper styles also did not express the requested handheld-console, TV and cyberpunk themes.

## What changed

- A straight flank at **X=135 mm left / X=25 mm right**, with a low plate continuing past the high frame.
- **16 intentional case corners**, each with an analytical **1.2 mm radius**. Case size is approximately **118.1 × 93.8 mm**, 8.1 mm narrower than revG.
- A rounded **24 × 56 mm frame**, ending before the thumb at Y=67 mm. Handheld, Retro TV and Cyberpunk add **0.6 mm raised details** to the 16.6 mm roof height. Plain styles remain available.
- Both KiCad outlines match the CAD proposal. All 36 switch positions/angles and all footprint/net data are preserved.

The power-switch reference still projects 1.5 mm past the case; it is the existing functional access exception. The TV treatment surrounds the real portrait LCD rather than implying a landscape screen.

## Evidence

| Check | Artifact |
|---|---|
| Continuous flank, corner count, switch margins, board/cavity fit | [Outline acceptance](../validation/revH-outline.json) |
| Exact Piantor layout, reference cap choices and complete selected configurations | [KLP qualification](../validation/revH-keycaps.json), `tools/check_layout.py` |
| Closed parts, six covers per half, component and USB intersections | [Native geometry](../validation/revH-mechanical.json) |
| Real FreeCAD configuration, height edit, save/reopen | [Editable source check](../validation/revH-freecad.json) |
| KiCad outline, preserved footprint/net state, unresolved DRC | [Electrical readback](../validation/revH-electrical.json) |
| Exact current geometry in the viewer | [Viewer provenance](../validation/revH-viewer.json) |

Screenshots and renders come from exported geometry. The theme comparison colors the raised faces to illustrate optional paint; each supplied frame is one printable solid. Actual printing, fasteners, cables, retention, firmware, BLE, charging and power measurements remain unfinished.

## Bounded correction review

Two independent read-only reviews agreed on the straight-flank correction and identified the stale PCB wing, possible thumb/frame collisions, service-opening access and the power-switch exception. Their dispositions are recorded in the [design review](../validation/revH-design-review.json).

The prior outline was inherited from revF and was not checked against a continuous-flank requirement. RevH adds a direct geometric acceptance check for the marked side, plus synchronized board-outline readback and renewed cap qualification. Historical revisions remain available.

The height-edit test also exposed a FreeCAD boolean failure with identical curved loft sections. Constant-section covers now use native extrusions; only tapered plain covers use lofts. Recompute, height and save/reopen assertions must pass before publication. This correction does not establish physical fit.

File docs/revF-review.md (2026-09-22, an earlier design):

# Historical revF editable-study review

**Scope: revF editable CAD and visualization, not manufacturing approval.**
Two independent reviews examined geometry, the CAD/ECAD workflow and risks; a second round compared the recessed battery and open frame proposal.

| Finding | Resolution / remaining state at revF |
|---|---|
| Moving the controller without lowering the battery intersects USB and cell | Cradle lowered through a real PCB opening; nominal cell/USB separation 1.4 mm |
| Display, header, JST and supports can overlap after alignment | Supports rebuilt from PCB level; JST/reset/power switch relocated; modeled solids separated |
| STEP import does not deliver parametric case editing | Native FCStd with sketches, operations and parameters; edit/save/reopen tested |
| Small opening and copper margins | 0.15 mm cradle/opening; 0.22 mm pad/edge. DRC fails the configured 0.5 mm rule; retained as unresolved |
| Shorter frame does not imply smaller total width | Width ≈126.2 mm; depth ≈94.5 mm; frame top 16.6 mm |
| Zero overhang lacks tolerance allowance | USB only 0.045 mm behind the neighboring cap in plan; nominal alignment, not physical guarantee |
| Retainer and removable parts lack service tests | Fastening, wiring, removal paths and fit remain open |

Both reviewers supported publishing the study with digital evidence and explicit limits. Manufacturing objections remained unresolved. Eight baseline files retained their hashes during both review rounds before attributable edits began.

The previous STEP assembly allowed inspection but lacked the needed parametric editing. RevF added FCStd source and edit/reopen checks. Images and viewer inputs were linked by hashes to detect stale representations. PCB/CAD comparison used real import and separate readback; a failed DRC was not relabeled as hardware approval.

RevG subsequently adds separate keycap-envelope checks: revF solid intersection checks did not cover the KLP meshes. [Current review](revG-review.md).

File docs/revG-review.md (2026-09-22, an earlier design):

# RevG review and verification scope

Two independent read-only reviews examined the same clean revF snapshot: one mechanical/domain review and one adversarial reliability review. The 12 enumerated input hashes remained unchanged during review. Both recommended a complete Choc-stem catalog with per-configuration qualification and opaque interchangeable covers using the existing mounts.

| Finding | Disposition |
|---|---|
| **High:** old solid intersection checks excluded KLP mesh bodies | Added dedicated keycap configuration checks: unchanged convex XY envelopes, frame clearance and a nominal travel/plate bound |
| **High:** a Choc stem does not imply every body fits every position | 38 files catalogued; 28 have qualified reference positions. Recheck each mixed configuration. Keep 1.5U unavailable, with the conservative test’s limits stated |
| **High:** `90deg` changes stem axis, not simply the file’s visual pose | Derive orientation from actual stem geometry; rotate the cap 90°/270° while retaining switch centers and angles |
| **Medium:** tilted caps have a different mesh origin | Align actual bottom stem tips to one nominal datum; retain physical seating as unresolved |
| **Medium:** rails might be mistaken for display supports | Preserve the independent sled; replace only outer covers with a common cavity/window/mount interface |
| **Medium:** covers could block plugs, switches or screws | Check each style against component envelopes and a 12 × 5 mm USB plug corridor; preserve switch/reset openings and recessed screw access. Real tools/cables remain untested |
| **Medium:** appearance-only swaps could diverge between viewer and CAD | One JSON schema, unchanged source meshes and a transactional FreeCAD macro; GLB carries the selected configuration |
| **Medium:** new retention/magnets or metal covers add unverified behavior | Keep polymer screw-mounted covers; no new magnets or snap-fit mechanism. RF and physical fastening remain open |

No material disagreement remained in the design review. This supports publication as a digital study, not fabrication, purchases or hardware acceptance.

## Bounded correction

The first closed-cover test detected **2.717649 mm³** of intersection with the controller’s front corners. The correction added a 0.3 mm nominal controller clearance cut next to the USB opening without increasing the bay outline. The same component/cover checks were rerun for all styles and both halves.

A visual inspection also caught side slits in the wide-bevel variant: its upper taper crossed the shared cavity before the roof began. The taper now starts at the roof underside, preserving opaque side walls. Closed solids alone would not have caught this appearance defect; the comparison render is part of the review.

The old GLB download filename still said revE. It now takes the current scene revision, and the browser test checks both filename and selected-configuration metadata. Render and viewer receipts link their current geometry inputs so stale imagery can be detected.

The Typeractive source check also found different socket/switch/button parts and a battery too wide for allowance in the existing cavity. They are documented as unqualified alternatives; the current hardware reference was not silently changed.

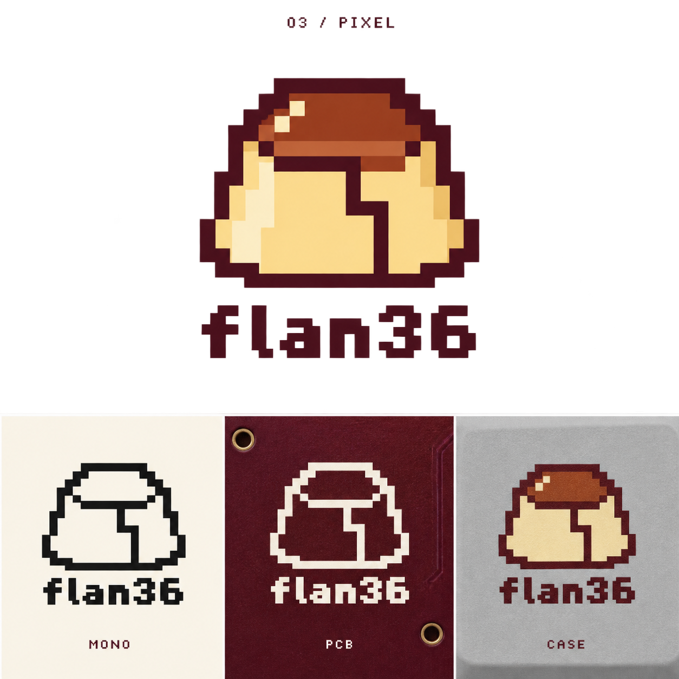
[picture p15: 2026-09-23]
docs/images/branding/flan36-pixel-concept.png

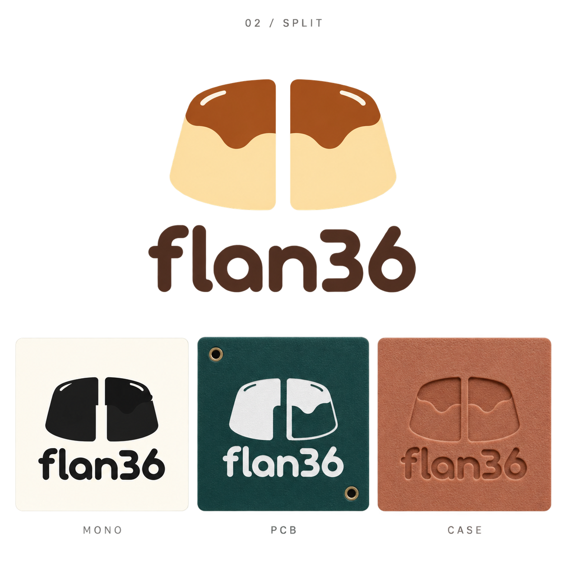
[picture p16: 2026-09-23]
docs/images/branding/flan36-split-concept.png

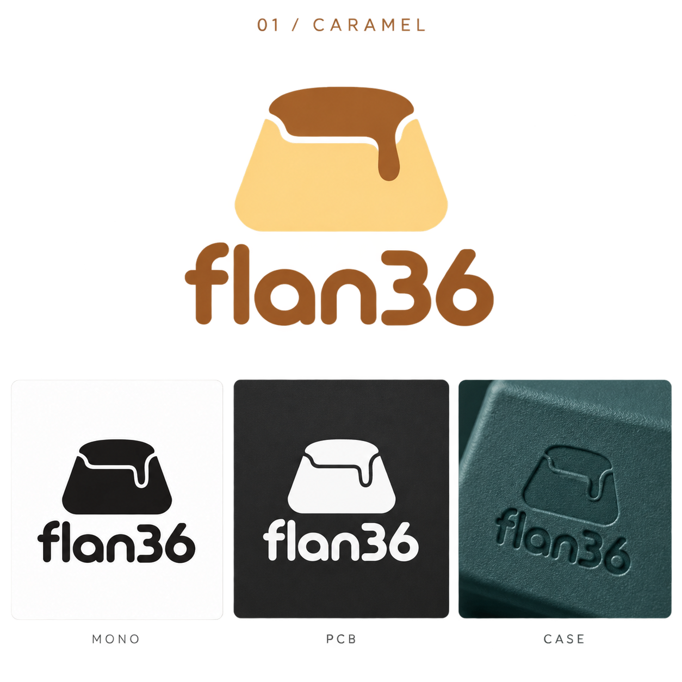
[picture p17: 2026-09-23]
docs/images/branding/flan36-caramel-concept.png

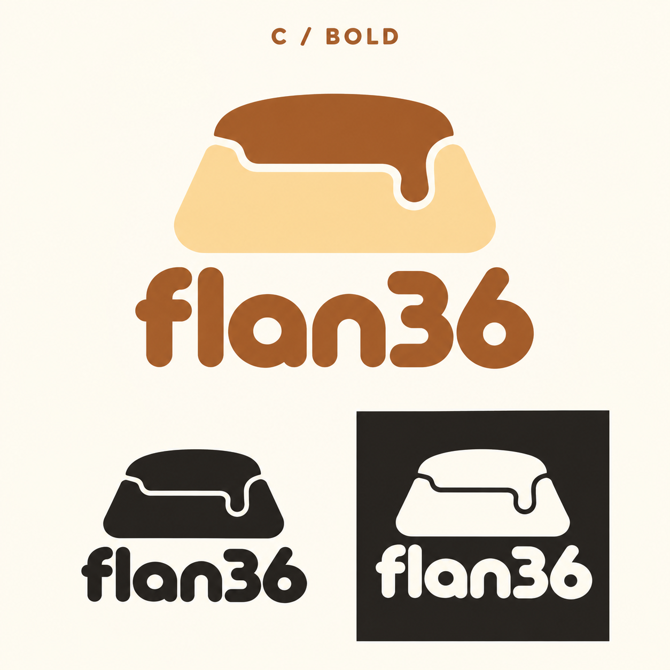
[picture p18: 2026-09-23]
docs/images/branding/flan36-caramel-bold.png

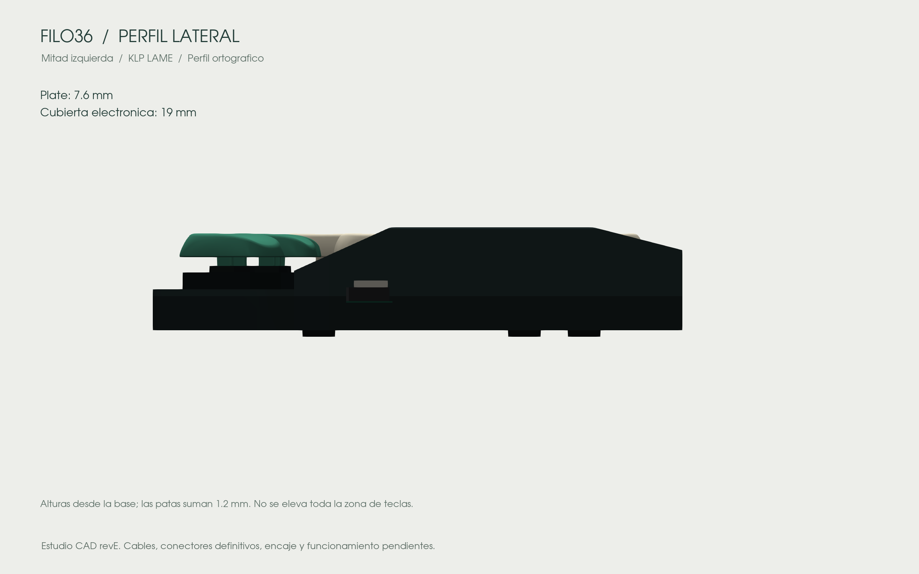
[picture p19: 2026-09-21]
docs/images/revE-side.png

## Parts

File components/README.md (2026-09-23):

# Component models

These models make the assembly easier to inspect. They are **nominal representations**, not a claim of measured fit or manufacturer CAD.

| Part | Geometry and appearance | Evidence / remaining limit |
| --- | --- | --- |
| nice!nano v2 | Black rounded PCB, ENIG contacts, mid-mount USB-C shell and tongue, separate ICs, crystals, passives and LEDs | Official identity, 3.2 mm overall thickness and mid-mount USB. PCB 17.78 × 33.1 mm and total length 34.624 mm use a community drawing. Individual package placement/heights are reconstructed from photographs. |
| nice!view | 14 × 36 × 2.9 mm stack, five contacts, glass and backing; 10.744 × 25.28 mm active image | Official module drawing and Sharp panel specification. Preserve the 14.2 × 36.2 mm V-cut reserve for fit. Glass/flex assembly positions remain nominal. |
| Choc v1 | KiSwitch housing, pins and moving stem; original geometry, recolored | Generic Choc v1 community CAD; not a measured Pro Red specimen. KLP insertion and travel are not physically verified. |
| PCM12 / TL3342 | KiCad STEP geometry and original face materials | Registered to the existing KiCad footprints. Library models, not toleranced manufacturer assemblies. |
| Choc hotswap socket | Licensed source CAD is included for inspection | Assembly datum and floor clearance remain unqualified; it is not silently placed using its bounding-box center. |
| Batteries, battery connector, MCU sockets and leads | Existing dimensional reserves | Finished pouch seams, contacts, solder, terminations and strain relief still require measurement. |

The right half uses the **same** commercial nano/display geometry, translated into place. The power switch is rotated to its footprint. Neither module is mirrored.

FreeCAD, the web viewer and the revI KiCad relative STEP models share this nominal geometry. The STEP export is reimported and compared with the native solids at each existing footprint datum; PCB files and model references remain unchanged. [Readback](../validation/revI-pcb-component-models.json).

The controller support has scalloped upper ledges. These keep clear of a 1.05 mm radius reserve around the underside pads. They do not establish solder tolerance or retention force.

The nice!view PCB remains 8.8 mm above the main PCB in this study. The Typeractive connector publishes 7 mm installed height. **That connection is still unresolved**; the visual model does not stretch a pin to hide the difference.

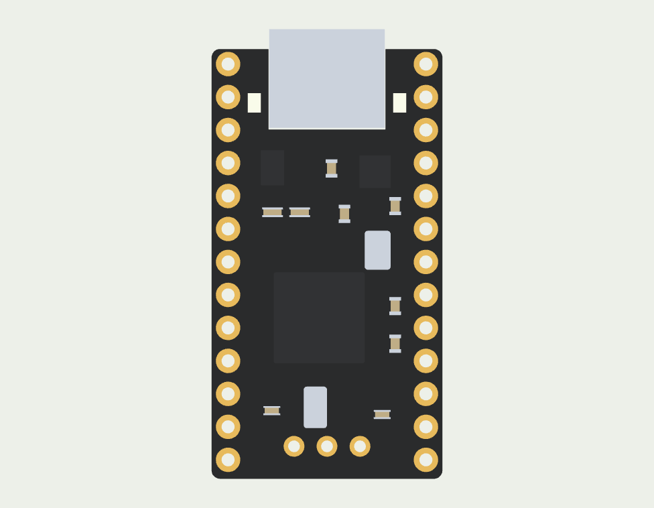
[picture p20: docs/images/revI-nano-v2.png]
Nominal nice!nano v2 reconstruction in the explorer


## Sources

- [nice!nano product specifications](https://nicekeyboards.com/nice-nano/) and [official v2 pinout, both faces](https://nicekeyboards.com/docs/nice-nano/pinout-schematic/).
- [Jordan Banasik / Woovie nominal v2 drawing](https://github.com/Woovie/nicenano-v2-model/tree/88099bcecdf2b60a0ec73131b132a182da03302b), CC0. Used as a dimensional reference; no recolored Pro Micro model is used.
- [nice!view mechanical drawing](https://nicekeyboards.com/docs/nice-view/pinout-schematic/) and [Sharp LS011B7DH03 catalogue](https://global.sharp/products/device/catalog/pdf/sharp_device202109_e.pdf).
- [KiSwitch source revision](https://github.com/kiswitch/kiswitch/tree/aefcf65038d48d2666ff14530d482be3c350fa6e), under its [MIT option](sources/KiSwitch-MIT.txt).
- [KiCad library license and exception](https://www.kicad.org/libraries/license/). Imported STEP files are CC-BY-SA-4.0 with the library exception. Original colors are preserved; only placement changes.

Exact asset URLs, hashes and licenses: [sources.json](sources.json). Official photographs are references, not images relicensed by this project. Parametric reconstruction: [components.py](../tools/freecad/components.py).

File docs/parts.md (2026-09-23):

# Parts and buying guide

**One complete 36-key split. Quantities cover both halves.**

This is a planning BOM for the revI mechanical study and PCB outline. **It is not a verified build kit:** the PCBs are unrouted, and exact connectors, magnetic retention and printed threads still need physical tests. Store links identify actual products; they do not certify interchangeability.

[Typeractive shopping list](#typeractive-shopping-list) · [Controllers](#controllers) · [Displays](#displays) · [Switches](#switches-and-hot-swap) · [Battery](#battery) · [Connectors](#removable-connectors) · [Small parts](#small-electrical-parts) · [Printed parts](#printed-parts)

## Typeractive shopping list

| Item | Quantity / store selection | Fit status |
|---|---|---|
| [nice!nano v2](https://typeractive.xyz/products/nice-nano) | **2 units** | Selected controller; final socket height pending |
| [nice!view](https://typeractive.xyz/products/nice-view) | **2 units**, or 1 for the fallback | Selected display; included connector does not establish stack fit |
| [Choc v1 switches](https://typeractive.xyz/products/choc-switches) | **4 packs of 10**; Pro Red baseline | 36 required, 4 spares |
| [Kailh hot-swap sockets](https://typeractive.xyz/products/hotswap-sockets) | **4 packs of 10; select Choc** | Do not select MX |
| [1N4148W SMD diodes](https://typeractive.xyz/products/smd-diodes) | **4 packs of 10** | SOD-123 family; verify supplied marking/footprint |
| [Machine sockets and pins](https://typeractive.xyz/products/machine-sockets-and-pins) | **2 kits** | Store uses Mill-Max **310**, study references **315**; substitution needs height/pin check |
| [EZ-Solder sockets/headers](https://typeractive.xyz/products/ez-machine-sockets-and-headers) | **2 kits**, instead of the preceding kits | Easier header handling; taller, not qualified in this stack |
| [5-pin sockets](https://typeractive.xyz/products/5-pin-sockets) | Optional **1 pack of 2** | Extras; nice!view already includes sockets/pins. Published 7 mm installed height differs from our nominal stack |
| [110 mAh battery](https://typeractive.xyz/products/lithium-battery-110mah) | **2**, connector variant to resolve | Supported nominal envelope in the shared 12.5 mm aperture; physical pack fit pending |
| [Battery jack](https://typeractive.xyz/products/battery-jack) | **1 pack of 2** | JST S2B-PH-K reference; orientation/footprint not closed |
| [Power switch](https://typeractive.xyz/products/power-switch) | **1 pack of 2** | Alps part differs from the C&K reference; footprint change/check required |
| [Reset button](https://typeractive.xyz/products/reset-button) | **1 pack of 2** | Panasonic part differs from the E-Switch reference; not a drop-in approval |

The selected Adafruit battery, custom PCB and printed parts are outside this store list. Prices, stock and shipping eligibility can change; check the selected variant and delivery destination at checkout. No purchases have been made.

## Controllers

<a href="https://typeractive.xyz/products/nice-nano">nice!nano v2.0 — supplier product photo</a>

**2 × nice!nano v2.** nRF52840 wireless controllers with USB-C and battery charging. They provide the intended BLE link between halves and to the host.

**Technical reference:** [v2 pinout and schematic](https://nicekeyboards.com/docs/nice-nano/pinout-schematic/). **Full documentation:** [nice!nano](https://nicekeyboards.com/docs/nice-nano/). **Buy:** [Typeractive](https://typeractive.xyz/products/nice-nano).

Alternatives: clones require independent pinout, charger and idle-current checks. XIAO or other controller formats require a PCB and mounting redesign. No alternative is approved as a direct replacement.

## Displays

<a href="https://typeractive.xyz/products/nice-view">nice!view — supplier product photo</a>

**2 × nice!view**, with a single left display as the fallback. Reflective memory LCD; selected for low power. Each cover leaves the glass visible and hides the surrounding electronics.

**Technical reference:** [dimensions, pinout and schematic](https://nicekeyboards.com/docs/nice-view/pinout-schematic/). **Full specifications/setup:** [nice!view documentation](https://nicekeyboards.com/docs/nice-view/). **Buy:** [Typeractive](https://typeractive.xyz/products/nice-view).

A separate board PDF datasheet is not linked by the manufacturer; its dimensioned drawings and schematic are the authoritative board references. OLED offers dark-room visibility at a power cost. E-paper needs a different mount and firmware. Neither fits this design as a drop-in alternative.

## Switches and hot-swap

<a href="https://typeractive.xyz/products/choc-switches">Kailh Choc v1 Low Profile Switches — supplier product photo</a>

**36 × Kailh Choc v1; 40 provides spares.** Pro Red 35 gf is the baseline; Pink 20 gf is lighter, Red 50 gf firmer, Brown tactile and White clicky. Silent Ambients are another Choc-family option to measure before adopting.

**Technical information:** [Kailh PG1350 family](https://www.kailhswitch.com/info/kailh-kl-switches-pg1350-series-23772219.html). **Variant specifications and purchase:** [Typeractive Choc v1](https://typeractive.xyz/products/choc-switches). **Silent alternative:** [LowproKB Ambients](https://lowprokb.ca/products/ambients-silent-choc-switches).

An exact Pro Red manufacturer PDF has not been verified here; the family page is not a substitute for a variant-specific drawing. Choc v2/MX-stem switches are outside this build.

<a href="https://typeractive.xyz/products/hotswap-sockets">Kailh Hotswap Sockets — supplier product photo</a>

**36 × Kailh CPG135001S30 Choc sockets; 40 provides spares.**

**Datasheet/drawing:** [Kailh CPG135001S30 PDF](https://www.kailhswitch.com/Content/upload/pdf/202115927/CPG135001S30-data-sheet.pdf). **Info and purchase:** [Typeractive — select Choc](https://typeractive.xyz/products/hotswap-sockets). The product photo includes both families; the **MX** variant is incompatible.

## Battery

<a href="https://www.adafruit.com/product/1570">Adafruit 1570 battery — supplier product photo</a>

**CAD reference: 2 × Adafruit 1570, protected 1S LiPo, sold as 100 mAh.** The model uses the product page’s **11.5 × 31 × 3.8 mm** envelope; two 105 mm lead storage paths are modeled as a nominal reservation.

**Datasheet:** [supplier-linked PKCELL PDF](https://cdn-shop.adafruit.com/product-files/1570/1570datasheet.pdf). **Full information and purchase:** [Adafruit 1570](https://www.adafruit.com/product/1570). The linked PDF names a **401230 / 105 mAh** cell, while the listing says 100 mAh: confirm the actual supplied pack and its dimensions before closing the cradle. The product page limits charging to **100 mA or less**; the nice!nano charger configuration must respect the actual cell’s limit.

<a href="https://typeractive.xyz/products/lithium-battery-110mah">Lithium Battery 110mAh — supplier product photo</a>

**Typeractive alternative: 301230, 110 mAh, 3 × 12 × 30 mm.** [Product and connector variants](https://typeractive.xyz/products/lithium-battery-110mah). The black PH connector version has shorter leads; the white version includes a mating wired jack. No cell-specific datasheet is linked on the listing.

**Both profiles use the same case, PCB opening, cradle and cage.** Select the battery in **Battery** in the sidebar in the viewer; configuration JSON and FreeCAD retain the choice per half.

| Profile | Nominal W × L × H | Aperture side gap | Gap below rigid cage roof |
|---|---|---:|---:|
| Adafruit 1570 | 11.5 × 31 × 3.8 mm | 0.50 mm per side | 0.40 mm |
| 301230 | 12 × 30 × 3 mm | 0.25 mm per side | 1.20 mm |

These are nominal clearances, not maximum finished-pack tolerances. Confirm protection-board wrapping, insulation at PCB edges, lead exit, connector polarity and charging limits on the delivered pack. The smaller pack can move within the cage; its full translation envelope remains clear of the modeled leads. No autonomy estimate is promised.

## Removable connectors

<a href="https://typeractive.xyz/products/machine-sockets-and-pins">Machine Sockets and Pins — supplier product photo</a>

**Controller study reference:** 4 × 12-position Mill-Max **315-43-112-41-003000** strips and 48 compatible round pins, plus spares. [Manufacturer-authored datasheet, distributor mirror](https://static6.arrow.com/aropdfconversion/2e225be7d9212620894362dafa7ce735623fe9ca/315-43-112-41-003000.pdf).

**Store alternative:** [Typeractive machine sockets/pins](https://typeractive.xyz/products/machine-sockets-and-pins), **2 kits**, each for one controller. The listing specifies Mill-Max **310**; do not treat it as the modeled 315 part. [EZ-Solder](https://typeractive.xyz/products/ez-machine-sockets-and-headers) trades loose pins for headers and a slightly taller assembly. Exact mating height and pin selection remain open for both alternatives. Do not force square pins into turned sockets.

<a href="https://typeractive.xyz/products/5-pin-sockets">5-Pin Sockets — supplier product photo</a>

**Display connectors:** 2 × 5-position sockets and 10 matching pins. [Typeractive 5-pin sockets](https://typeractive.xyz/products/5-pin-sockets) are the included nice!view type, sold separately in pairs; 5 mm socket plus 2 mm display pin gives a stated 7 mm installation height. Our reference display PCB is **8.8 mm above the main PCB top**, so contact lengths and support height need reconciliation. No separate connector datasheet is linked.

[No-solder spring headers](https://typeractive.xyz/products/no-solder-spring-headers) require the supplier’s specified **0.8–0.9 mm holes** and different installed heights. They are not qualified for the current Flan36 hole/contact geometry. Do not buy them as an assumed shortcut.

## Small electrical parts

<a href="https://typeractive.xyz/products/smd-diodes">SMD Diodes — supplier product photo</a>

**36 × 1N4148W, SOD-123; four 10-packs give spares.** [Typeractive info/buy](https://typeractive.xyz/products/smd-diodes) · [Semtech datasheet](https://cdn.shopify.com/s/files/1/0618/5674/3655/files/Semtech-1N4148W.pdf?v=1670451309). Match package and cathode orientation to the final PCB.

<a href="https://typeractive.xyz/products/battery-jack">Battery Jack — supplier product photo</a>

**2 × battery jacks.** [Typeractive JST PH 2.0 mm](https://typeractive.xyz/products/battery-jack) · [JST S2B-PH-K drawing](https://cdn.shopify.com/s/files/1/0618/5674/3655/files/JST-S2B-PH-K.pdf?v=1670451309). Connector orientation and battery polarity must match the final PCB and pack; the CAD block does not settle the footprint.

<a href="https://typeractive.xyz/products/power-switch">Power Switch — supplier product photo</a>

**2 × power switches.** CAD/PCB reference: **C&K PCM12SMTR**, [manufacturer datasheet](https://www.ckswitches.com/media/1424/pcm.pdf). Typeractive sells **Alps SSSS811101**, [product information](https://typeractive.xyz/products/power-switch) · [Alps datasheet](https://cdn.shopify.com/s/files/1/0618/5674/3655/files/ALPS-SSSS811101.pdf?v=1670451309). The photo is the **Alps alternative**. Different part/footprint; not approved as interchangeable.

<a href="https://typeractive.xyz/products/reset-button">Reset Button — supplier product photo</a>

**2 × reset buttons.** Reference: **E-Switch TL3342F160QG**, [full product information](https://www.e-switch.com/product/tl3342-series-low-profile-smt-tactile-switch/) · [datasheet](https://configured-product-images.s3.amazonaws.com/2D/specs/TL3342F160QG.pdf). Typeractive sells **Panasonic EVQPUC02K**, [product information](https://typeractive.xyz/products/reset-button) · [Panasonic datasheet](https://cdn.shopify.com/s/files/1/0618/5674/3655/files/PANASONIC-EVQPUC02K.pdf?v=1670451309). The photo is the **Panasonic alternative**. Footprint and actuation height must be reviewed before substitution.

## Printed parts

Flan36 revI case CAD and KLP Lamé reference assembly

| Part | Quantity | Files / options |
|---|---:|---|
| KLP Lamé keycaps | 36 | [Variant guide](customize.md); [38 source STLs](../keycaps/variants); original preset: 28 Normal + 2 Homing + 6 Thumb |
| Case bases and key plates | 2 each | [Editable CAD, STEP and STL](cad.md) |
| Display frames | 2 | Handheld, Retro TV, Cyberpunk or three plain styles; separate color per half |
| Battery cradles and retainers | 2 each | Low saddle and rigid cage; cage feet captured under PCB |
| Controller supports and display sleds | 2 each | Independent from the cover |
| Printed spacers/washers | 6 | Check printed dimensions and screw fit |

**Technical source for keycaps:** [KLP Lamé files and print guidance](https://github.com/braindefender/KLP-Lame-Keycaps). No commercial datasheet applies to the custom printed parts; the FCStd and dimensioned parameters are their design source. PLA Basic, PETG HF and ABS are candidate materials, not validated print profiles. Start with a fit coupon and three caps.

## Fasteners, cable and tools

- **6 × M2 × 6 low-head screws:** nominal NBK SLH envelope, Ø3.8 × 1.3 mm head. [Drawing](https://static.nbk1560.com/images/en/product/lowsmallheadscrew/SLH-TZB/SLH-TZB_1.pdf). **4 × M2 × 4:** NBK SSH envelope, Ø4 × 1.1 mm head. [Drawing](https://static.nbk1560.com/images/en/product/lowsmallheadscrew/SSH/SSH_1.pdf). Tap the printed Ø1.7 mm pilots M2; engagement is 2.2–2.4 mm. Thread strength remains untested.
- **6 × Ø2 × 3 mm neodymium magnets:** S-02-03-N reference, N45. [Full product information](https://www.supermagnete.de/stabmagnete-neodym-rund/stabmagnet-2mm-3mm_S-02-03-N) · [Datasheet](https://www.supermagnete.fr/data_sheet_S-02-03-N.pdf). Three stay in each base. Test the capture process without exceeding the specified 80°C magnet temperature.
- **6 × Ø2 × 4 mm ferromagnetic steel pins:** three per frame. The exact supplier/grade is still open; nonmagnetic stainless is unsuitable. Every additional pair of frames needs six more pins; the base magnets stay in place.
- **8 adhesive rubber feet:** approximately 1–1.5 mm. Their height adds to the case.
- **Insulation and removable retention:** small quantity; avoid loading the battery pouch. The rigid cage and captive inserts are digitally modeled; printed retention is untested.
- **1–2 USB-C data cables:** charging and firmware transfer. [Typeractive’s silicone cable](https://typeractive.xyz/products/silicone-usb-c-cable) is listed for power; its page does not establish data support. Do not assume it can flash firmware. Check plug dimensions against the opening.
- Fine-tip soldering iron, solder, flux, tweezers, cutters and a multimeter. The printer makes mechanical parts; the custom PCB needs fabrication after routing and DRC are complete.

## Sources and images

Original store links and pack quantities were checked on **2026-09-21**; battery specifications and magnetic hardware sources were revisited on **2026-09-22**. The current automated link check could not read the Arrow socket PDF (timeout) or the C&K PDF (403); those historical technical references remain listed, not freshly verified. Manufacturer/supplier documentation takes precedence over approximate CAD envelopes. Missing exact datasheets and unresolved substitutions are explicitly identified above.

Product photos are embedded from Typeractive/Adafruit and linked to their original listings. They remain the property of their respective owners; they are not relicensed under this repository’s license. They need internet access and are not bundled in the offline 3D viewer. Flan36 renders have separate [attribution](../ATTRIBUTION.md).

## What the component models represent

The explorer now distinguishes commercial model sources from fit reserves. See [component fidelity and dimensions](../components/README.md) for the nice!nano v2 reconstruction, nice!view drawing, licensed library models and the remaining connector/measurement gaps.

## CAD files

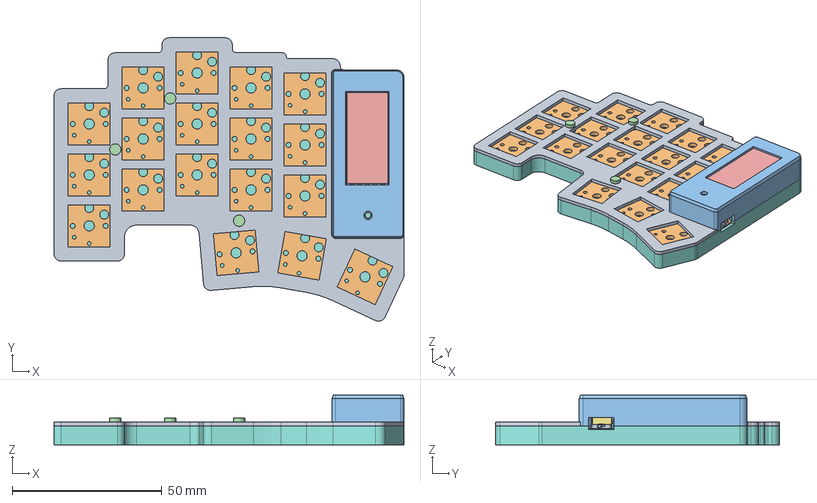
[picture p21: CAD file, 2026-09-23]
mechanical/revI/left-assembly.step
116.8 x 94.6 x 16.6 mm

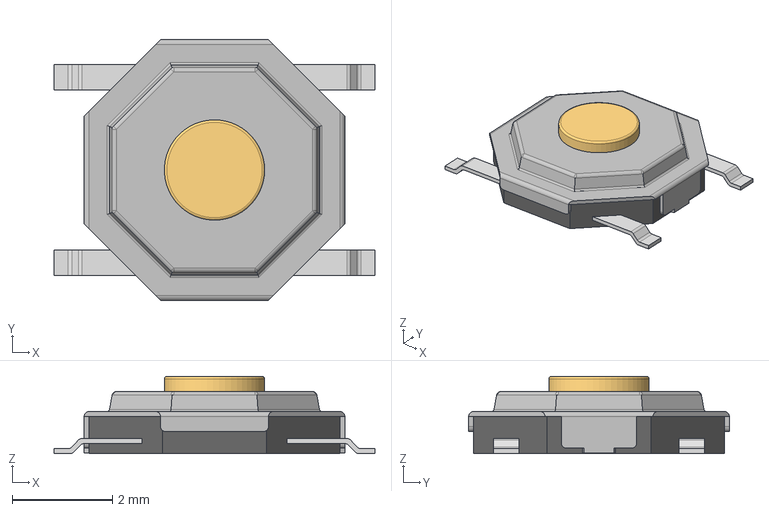
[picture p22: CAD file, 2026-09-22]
components/sources/SW_SPST_TL3342.step
6.40 x 5.20 x 1.54 mm

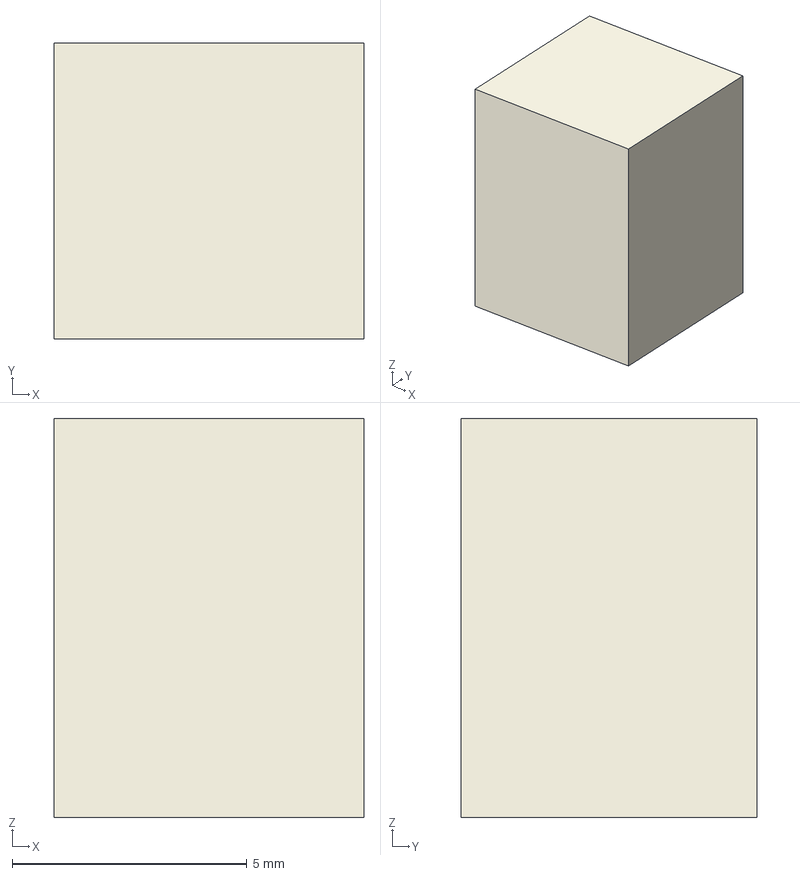
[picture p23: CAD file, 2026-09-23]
hardware/revI/models/right-jst.step
6.60 x 6.30 x 8.50 mm

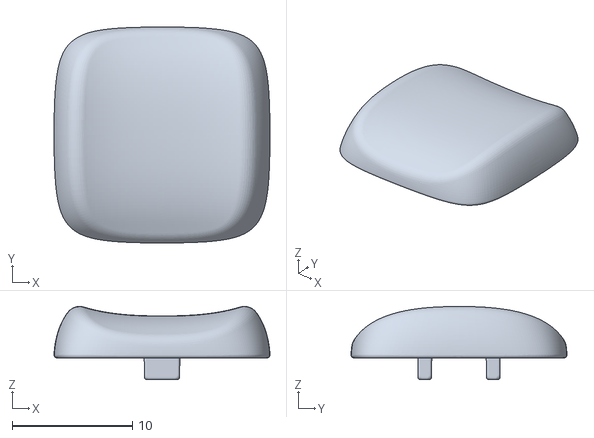
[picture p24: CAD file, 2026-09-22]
keycaps/variants/Choc_Stem_MX_Size_Saddle_90deg.stl
18.0 x 18.0 x 6.09

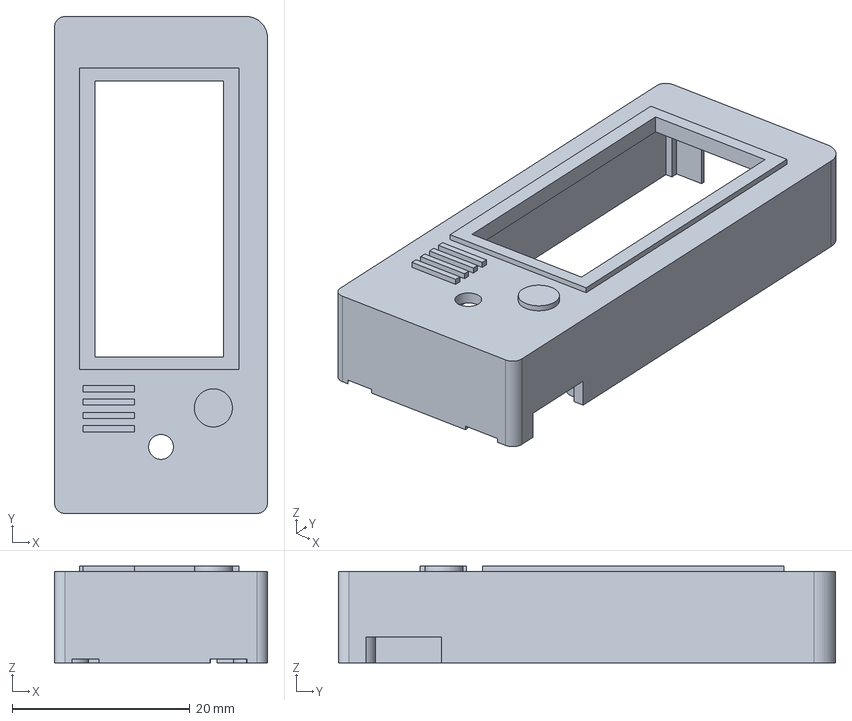
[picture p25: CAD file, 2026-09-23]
mechanical/revI/left-frame-tv.step
24.0 x 56.0 x 10.9 mm

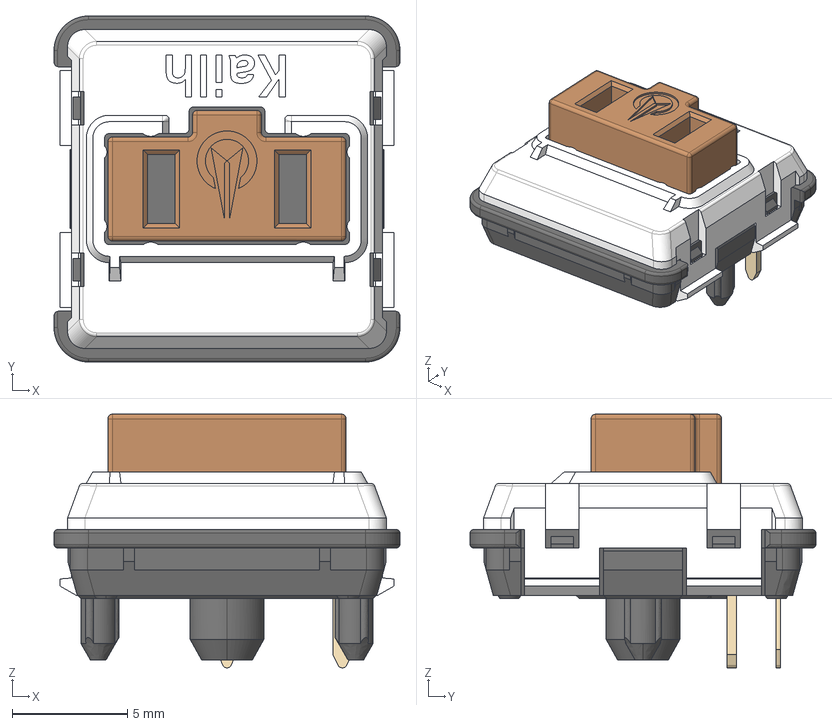
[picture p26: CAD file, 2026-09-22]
components/sources/SW_Kailh_Choc_V1.FCStd
15.0 x 15.0 x 11.0 mm
Upper_Housing
Lower_Housing
Stem
Pin_2
Pin_1

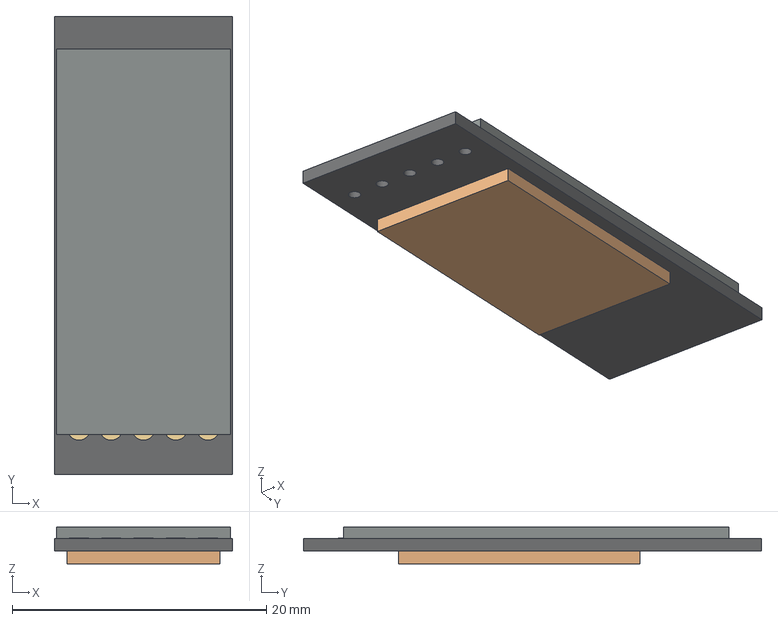
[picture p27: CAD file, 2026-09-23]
hardware/revI/models/right-display.step
14.0 x 36.0 x 2.90 mm

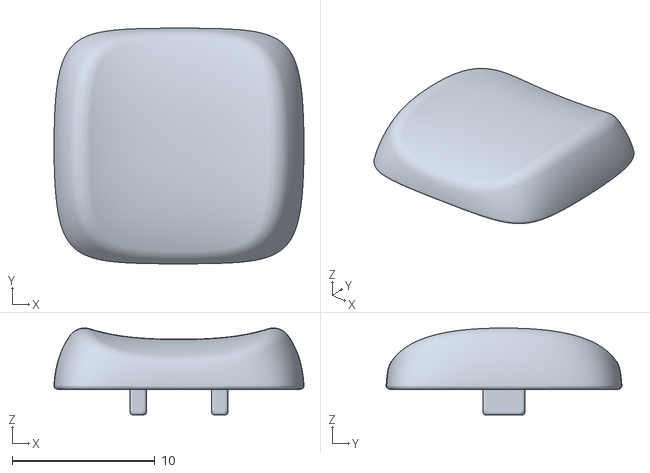
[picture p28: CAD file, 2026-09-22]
keycaps/variants/Choc_Stem_Choc_Size_Saddle.stl
17.5 x 16.5 x 6.08

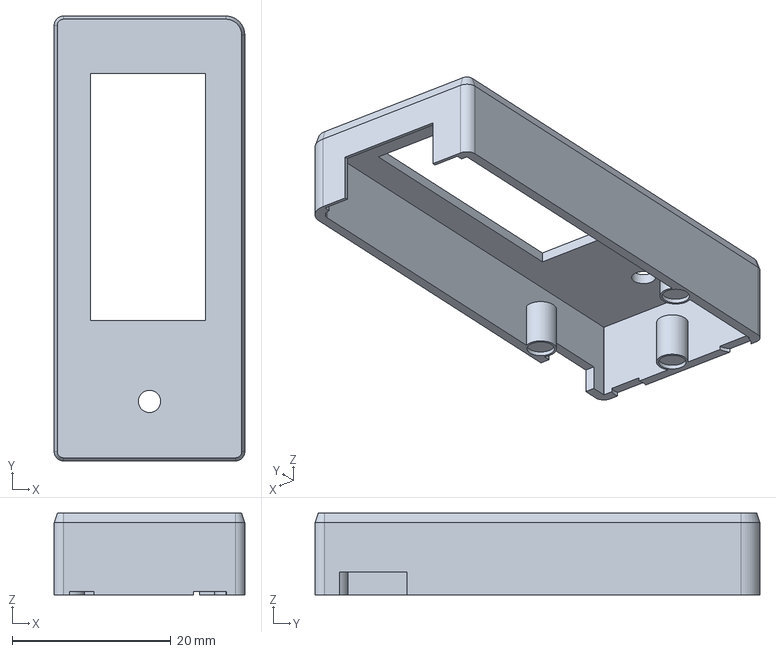
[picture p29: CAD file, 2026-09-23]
mechanical/revI/left-frame-bevel.step
24.0 x 56.0 x 10.3 mm

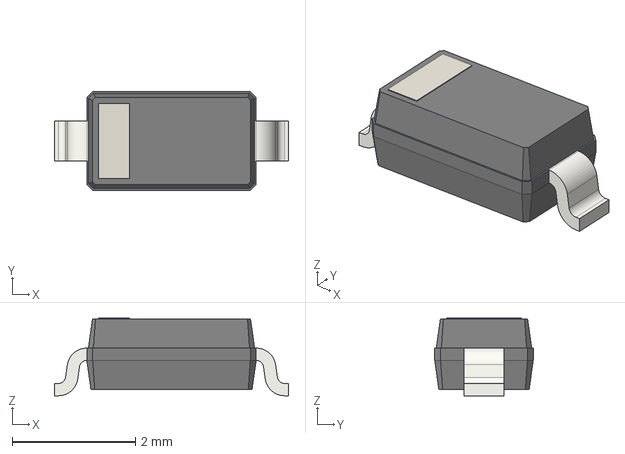
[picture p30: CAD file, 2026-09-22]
components/sources/D_SOD-123.step
3.80 x 1.60 x 1.26 mm

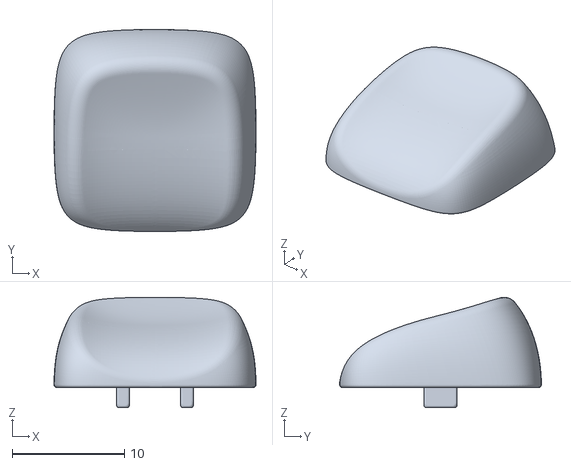
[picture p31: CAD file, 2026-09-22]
keycaps/variants/Choc_Stem_MX_Size_Saddle_Tilted.stl
18.0 x 18.0 x 9.84

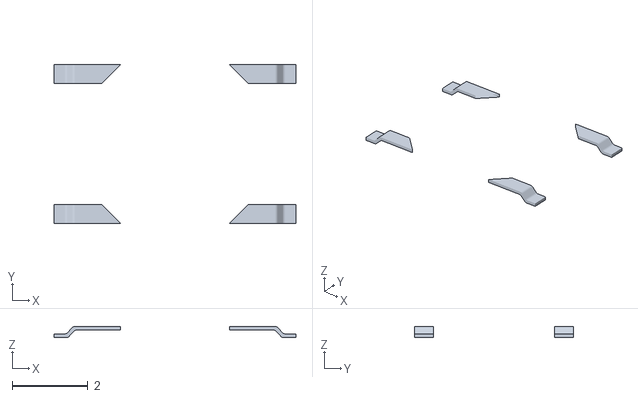
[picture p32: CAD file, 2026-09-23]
mechanical/revI/left-reset-visual-0.stl
6.40 x 4.20 x 0.3

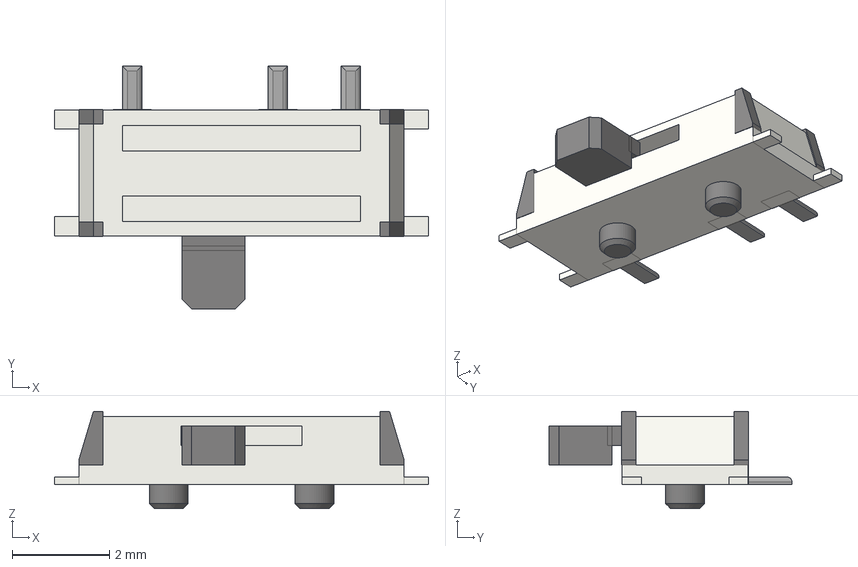
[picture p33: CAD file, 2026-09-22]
components/sources/SW_SPDT_PCM12.step
7.70 x 5.00 x 2.00 mm

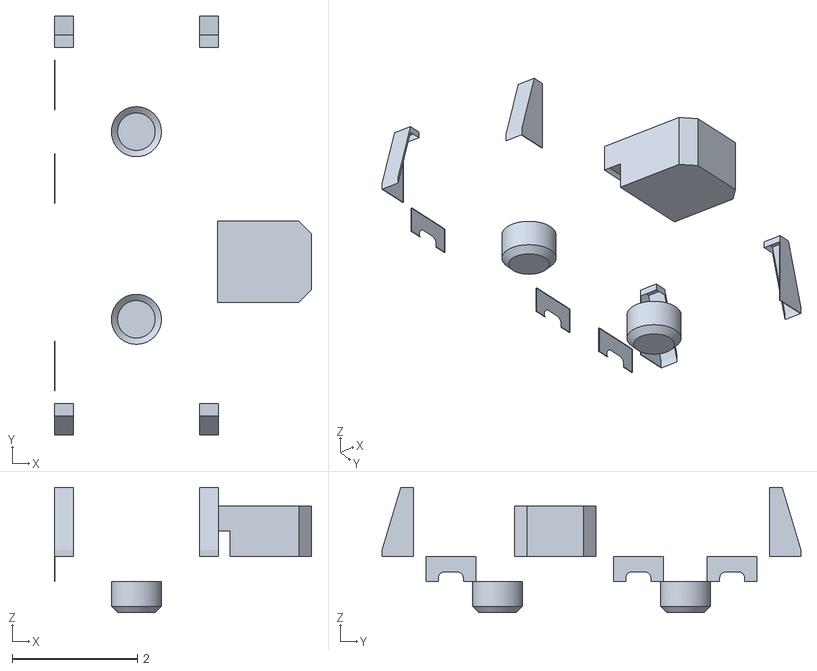
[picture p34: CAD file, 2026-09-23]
mechanical/revI/left-slider-visual-1.stl
4.11 x 6.70 x 2.00

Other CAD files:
mechanical/revI/right-assembly.step
hardware/revI/models/left-display.step
hardware/revI/models/choc-envelope.step
keycaps/variants/Choc_Stem_Choc_Size_Saddle_Homing_90deg.stl
components/sources/SW_Hotswap_Kailh_Choc_v1.FCStd
hardware/revI/models/left-jst.step
hardware/revI/models/left-mcu.step
hardware/revI/models/left-reset.step
hardware/revI/models/left-slider.step
hardware/revI/models/right-mcu.step
hardware/revI/models/right-reset.step
hardware/revI/models/right-slider.step
keycaps/variants/Choc_Stem_Choc_Size_1.5U_Normal.stl
keycaps/variants/Choc_Stem_Choc_Size_1.5U_Saddle_H.stl
keycaps/variants/Choc_Stem_Choc_Size_1.5U_Saddle_V.stl
keycaps/variants/Choc_Stem_Choc_Size_1.5U_Thumb_H.stl
keycaps/variants/Choc_Stem_Choc_Size_1.5U_Thumb_V.stl
keycaps/variants/Choc_Stem_Choc_Size_Normal.stl
keycaps/variants/Choc_Stem_Choc_Size_Normal_90deg.stl
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

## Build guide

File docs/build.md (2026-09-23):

# Build status

The current design is an inspectable digital prototype. Final Gerbers, a closed BOM and tested UF2 firmware are not available yet. Do not order the unrouted PCB studies as finished boards.

The intended sequence is:

1. Close the BOM and measure the actual components.
2. Print a Choc fit coupon and three KLP Lamé samples. Check stem fit, return and comfort before printing the full set.
3. After electrical layout passes review and DRC, assemble the PCBs and check continuity and polarity.
4. Flash each half and test all 36 keys.
5. Install the supported battery, controller, display and frames without loading the pouch or glass.
6. Verify BLE, charging, sleep/wake and measured power use.

PLA Basic and PETG HF are available for prototype trials; ABS is another case material. No filament/profile is qualified for the final parts yet. Print orientation and stem tolerances need physical tests. [Parts and alternatives](parts.md).

## Inspect the layout now

`design/layout.json` contains each half’s 18 key centers and angles in millimeters. The original Piantor boards and provenance are under `sources/` and [ATTRIBUTION.md](../ATTRIBUTION.md).

```sh
python3 tools/check_layout.py
python3 tools/render_layout.py
```

The checker compares all 36 positions/rotations with the original boards. The renderer regenerates the layout diagram. `sources/piantor/` contains the original **wired** reference boards, not Flan36’s wireless PCB designs.

## Magnetic frame and service

The frame is cosmetic and removable. The five internal structural screws per half keep the PCB and battery cage secured when the frame is lifted. Its three small locator lips resist sliding; magnets provide attraction. Do not use the frame as a carrying handle before retention is measured.

1. **Print the coupons first:** [magnet base](../mechanical/revI/coupon-magnet-base.stl), [frame target](../mechanical/revI/coupon-magnet-frame.stl), and [M2 thread](../mechanical/revI/coupon-m2-thread.stl). These are cropped production interfaces, at assembly coordinates. Orient the broad face on the bed and inspect every layer in the slicer.
2. **Pause and insert:** the base pocket is Ø2.3 × 3.2 mm for the Ø2 × 3 mm magnet; the frame pocket is Ø2.2 × 4.2 mm for the steel pin. Insert before the pocket closes and confirm the insert sits below the next nozzle path. The top coupon can print with its broad top face on the bed. Choose pauses from the actual sliced layer, not an assumed layer number.
3. **Qualify capture and heat:** enclosed inserts must stay captive after flexing and repeated removal. The reference magnet is rated to 80°C; verify its actual thermal exposure during printing. A low bed setting alone does not establish that. PLA Basic is the first coupon material to investigate; PETG HF and ABS remain alternatives to qualify.
4. **Check attraction and sliding:** reproduce the nominal 0.9 mm magnetic gap (pocket float allows roughly 0.7–1.1 mm before print tolerances). Check north-edge peel on a complete frame; a single-station coupon cannot establish whole-frame retention.
5. **Tap and test the M2 pilot:** use an M2 tap in the Ø1.7 mm printed hole, then test the specified screw without bottoming or stripping. Do not assume the screws are self-tapping.

For assembly, seat the insulating saddle, cell and cage before lowering the PCB over the cell. The cage’s wider feet remain below the board. Install the three plate spacers and structural screws, then the removable modules and frame. Do not compress the pouch. Actual lead exit and strain relief remain to be qualified.

For battery service: power off, disconnect USB and the battery, lift the magnetic frame, remove the modules/supports that obstruct access, remove the three plate screws and lift the plate, then remove the two short PCB screws and lift the PCB before withdrawing the captured cage. The magnetic cover alone does not release the battery. Final assembly/removal with real sockets and wires remains a physical acceptance step.

The latest [support study](slim-mount-study.md) finds that lifting the display and its sled together crosses the modeled battery leads during the first 0.5–2 mm. That route is not accepted for assembly instructions: lead routing or the release sequence must be corrected and checked before a physical build. The conflict affects the reference stack as well as the lower candidates.

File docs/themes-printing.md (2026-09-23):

# Make it yours

Open [the 3D explorer](https://eduarbo.github.io/flan36/), choose **Themes**, and pick a starting palette. Sixteen presets coordinate the case, frame and keycaps. Their previews use your selected shapes.

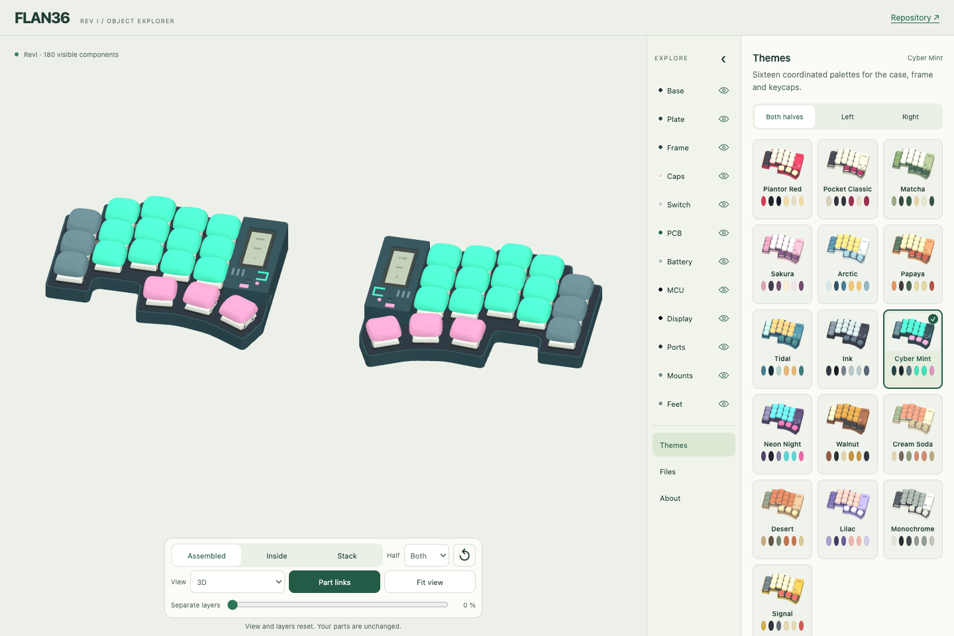
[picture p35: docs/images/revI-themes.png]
Theme gallery and coordinated rim/frame colors


1. Choose **Both halves**, **Left** or **Right**.
2. Pick a theme. It changes colors while preserving shapes, keycap geometry and installed covers.
3. In **Base**, edit the base/rim and key plate. In **Frame**, edit the body and raised details.
4. Enable **Match frame and rim** for continuous color. Editing either linked color updates the other.
5. Use **Files → Download print kit** for the selected parts.

Handheld, Retro TV, Cyberpunk, Cartridge, Arcade, Mecha and Kintsugi have four color regions. Smooth, Bevel and Facet use a single body color. Original design palettes remain available through **Restore design colors**.

Changing shapes preserves customized colors. An untouched original design adopts the new shape's original palette. Switching a frame reinstalls its cover; applying a color theme does not.

## Keep your configuration

Selections save automatically on this device. **Save configuration** downloads JSON for another browser or the FreeCAD configuration macro. JSON carries explicit colors, shapes and cover installation, so a preset name never changes an old saved design. Legacy JSON still loads.

Eye, Solo, camera and exploded views are inspection controls. They do not remove parts from the print kit. Unchecking **Printed display cover** does remove that cover and its targets from the selected assembly.

## Printable parts and joining

**Shells** exports each selected case, key plate and installed frame. **Complete printed set** also includes the battery saddle, cage, controller support, display support and three printed washers per half. Commercial parts and KLP keycaps are excluded; [keycap sources and fit guidance](customize.md#klp-lamé) remain separate.

The [support study](slim-mount-study.md) includes experimental plates with integrated washers and optional bases with integrated saddles. These reduce loose parts, not height, and are downloaded separately from the reference print kit.

- The structural case uses three M2 × 6 and two M2 × 4 screws per half. Tap the 1.7 mm pilot holes to M2.
- Each installed frame uses three captive Ø2 × 3 mm magnets and three Ø2 × 4 mm ferromagnetic pins.
- Cavities, guides and screw holes belong to the CAD geometry. Plan insertion pauses for captive hardware before slicing.
- There is no clip variant yet. A color or theme does not change the joining method.

The ZIP includes the selected geometry, JSON and a manifest with quantities, source hashes, units, colors and joining details. STL coordinates are the unchanged native assembly coordinates, in millimetres. Prepare orientation, supports, tolerances and your actual filament in the slicer.

This is prototype geometry. Print [fit coupons](cases.md) before a complete set. Neither magnets, tapped threads nor the whole assembly have physical acceptance yet.

## Color 3MF status

The generic 3MF files preserve the same triangles and assign surface regions; each part is translated onto Z=0. The manifest records that translation and all colors. They contain no printer or process profile.

**Bambu Studio color setup remains manual.** Its CLI preserves the painted regions, but does not automatically restore this generic file's color palette. Add four filament entries in **body, detail, accent, secondary** order using the manifest colors, then inspect each region. Automatic palette import and GUI save/reopen are not yet accepted. Use the unchanged STL if you prefer to paint the regions yourself.

Keycaps are included in global themes. For independent colors, row/column patterns and portable personal palettes, use [Caps → Colors](customize.md#keycap-colors). Selecting another keycap shape preserves its assigned color.

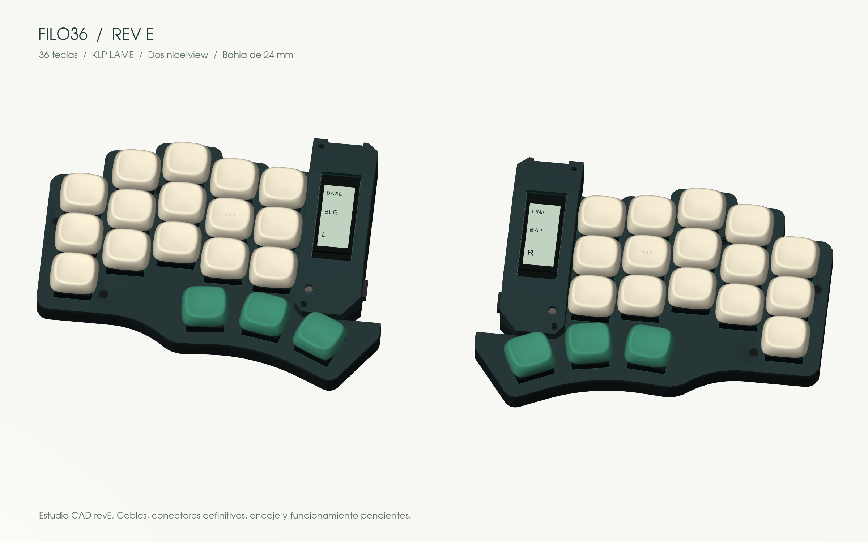
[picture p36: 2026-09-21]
docs/images/revE-assembled.png

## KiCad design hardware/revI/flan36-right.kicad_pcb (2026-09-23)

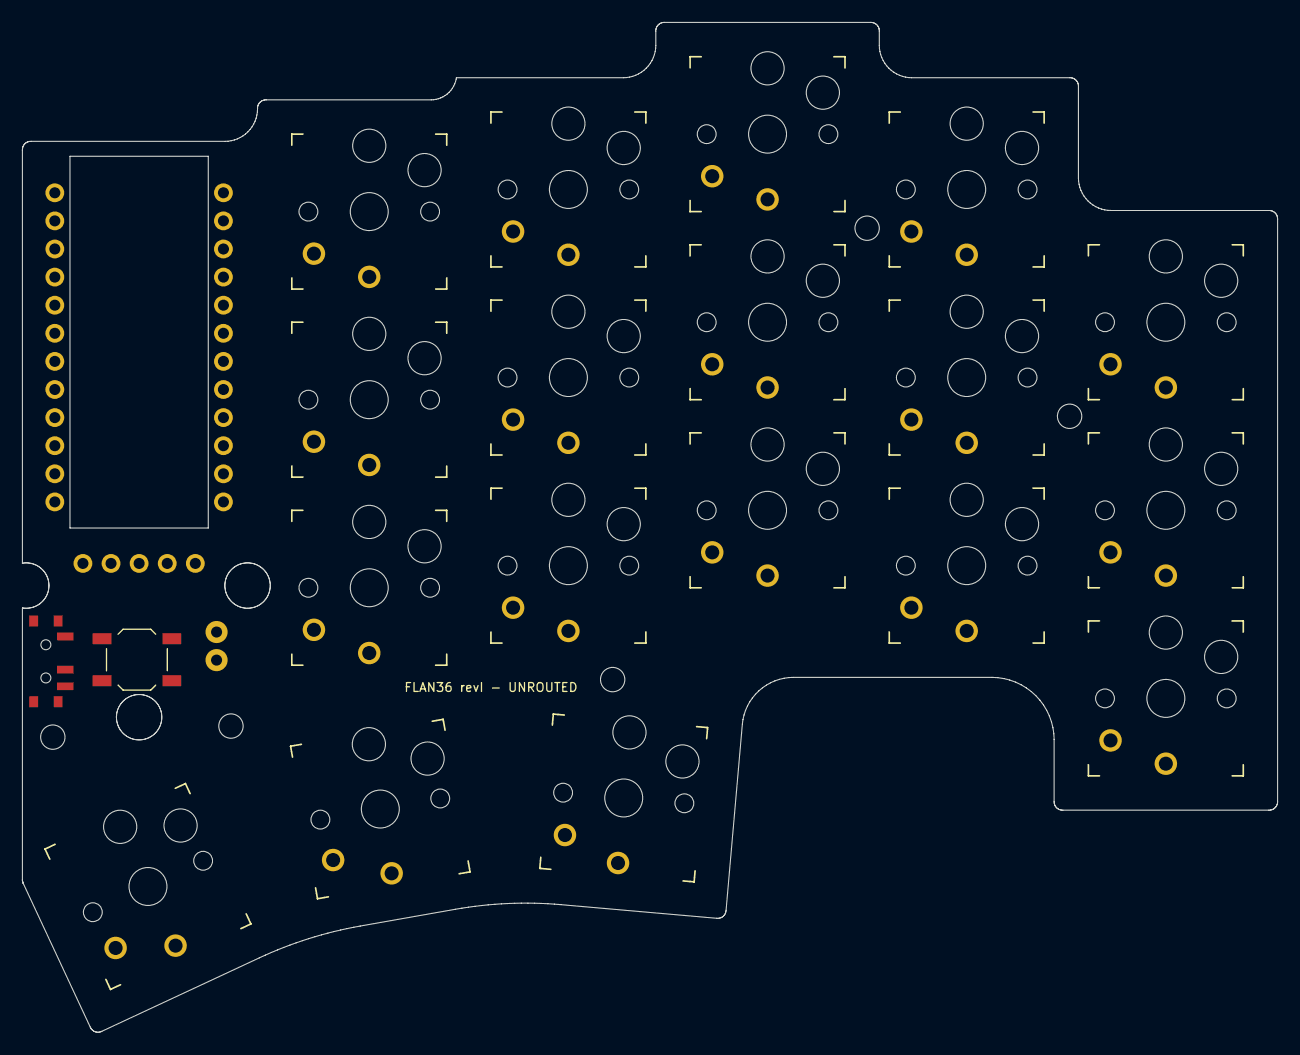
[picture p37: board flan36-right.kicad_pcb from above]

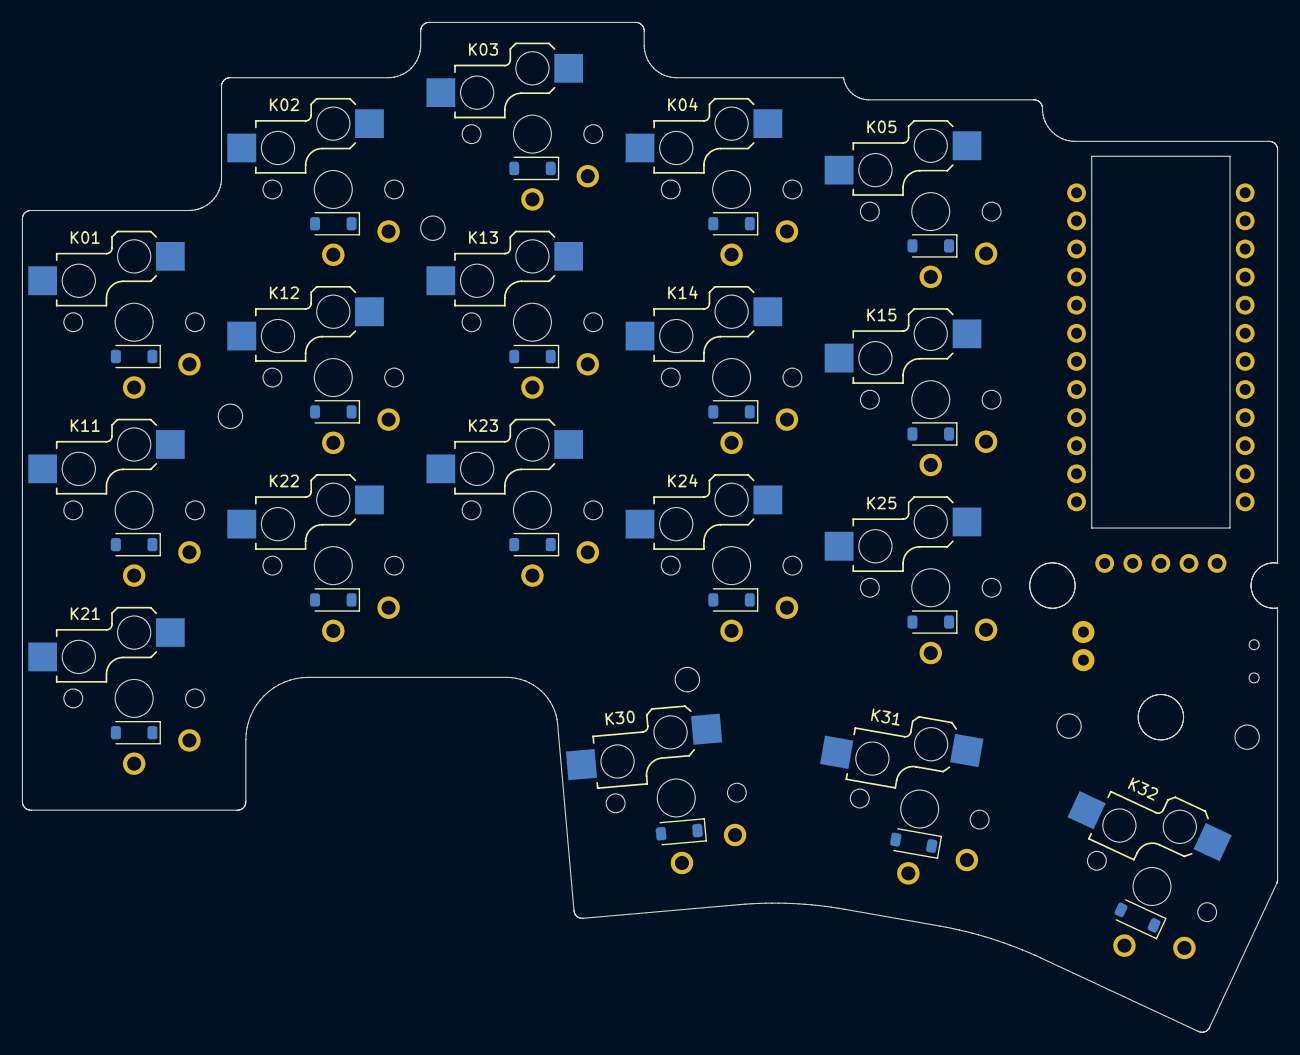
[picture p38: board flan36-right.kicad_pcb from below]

Board: 2 copper layers, 113.4 x 91.3 mm, 46 parts (18 on the bottom side), 36 nets, no tracks yet.

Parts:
D01, D02, D03, D04, D05, D11, D12, D13, D14, D15, D21, D22, D23, D24, D25, D30, D31, D32: D_SOD-123
H1, H2, H3, H4, H5: MountingHole_2.2mm_M2
J1: BATTERY_PIGTAIL; Battery_pigtail_2.54
J2: nice!view; nice_view_5pin
K01, K02, K03, K04, K05, K11, K12, K13, K14, K15, K21, K22, K23, K24, K25, K30, K31, K32: KEYSW; Kailh_socket_PG1350_optional
SW1: SW_SPDT_PCM12
SW2: SW_SPST_TL3342
U1: nice!nano v2; nice_nano_v2_standard_edge

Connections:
BAT_PLUS: J1.1, SW1.1
BAT_SW: SW1.2, U1.RAW
COL0: K30.1, U1.D6
COL1: K01.1, K11.1, K21.1, K31.1, U1.D7
COL2: K02.1, K12.1, K22.1, K32.1, U1.D8
COL3: K03.1, K13.1, K23.1, U1.D9
COL4: K04.1, K14.1, K24.1, U1.D10
COL5: K05.1, K15.1, K25.1, U1.D16
DISP_CS: J2.5, U1.D14
DISP_MOSI: J2.1, U1.D1
DISP_SCK: J2.2, U1.D0
GND: J1.2, J2.4, SW2.2, U1.GND1, U1.GND2, U1.GND3
K01_A: D01.2, K01.2
K02_A: D02.2, K02.2
K03_A: D03.2, K03.2
K04_A: D04.2, K04.2
K05_A: D05.2, K05.2
K11_A: D11.2, K11.2
K12_A: D12.2, K12.2
K13_A: D13.2, K13.2
K14_A: D14.2, K14.2
K15_A: D15.2, K15.2
K21_A: D21.2, K21.2
K22_A: D22.2, K22.2
K23_A: D23.2, K23.2
K24_A: D24.2, K24.2
K25_A: D25.2, K25.2
K30_A: D30.2, K30.2
K31_A: D31.2, K31.2
K32_A: D32.2, K32.2
RESET: SW2.1, U1.RST
ROW0: D01.1, D02.1, D03.1, D04.1, D05.1, U1.D2
ROW1: D11.1, D12.1, D13.1, D14.1, D15.1, U1.D3
ROW2: D21.1, D22.1, D23.1, D24.1, D25.1, U1.D4
ROW3: D30.1, D31.1, D32.1, U1.D5
VCC: J2.3, U1.VCC

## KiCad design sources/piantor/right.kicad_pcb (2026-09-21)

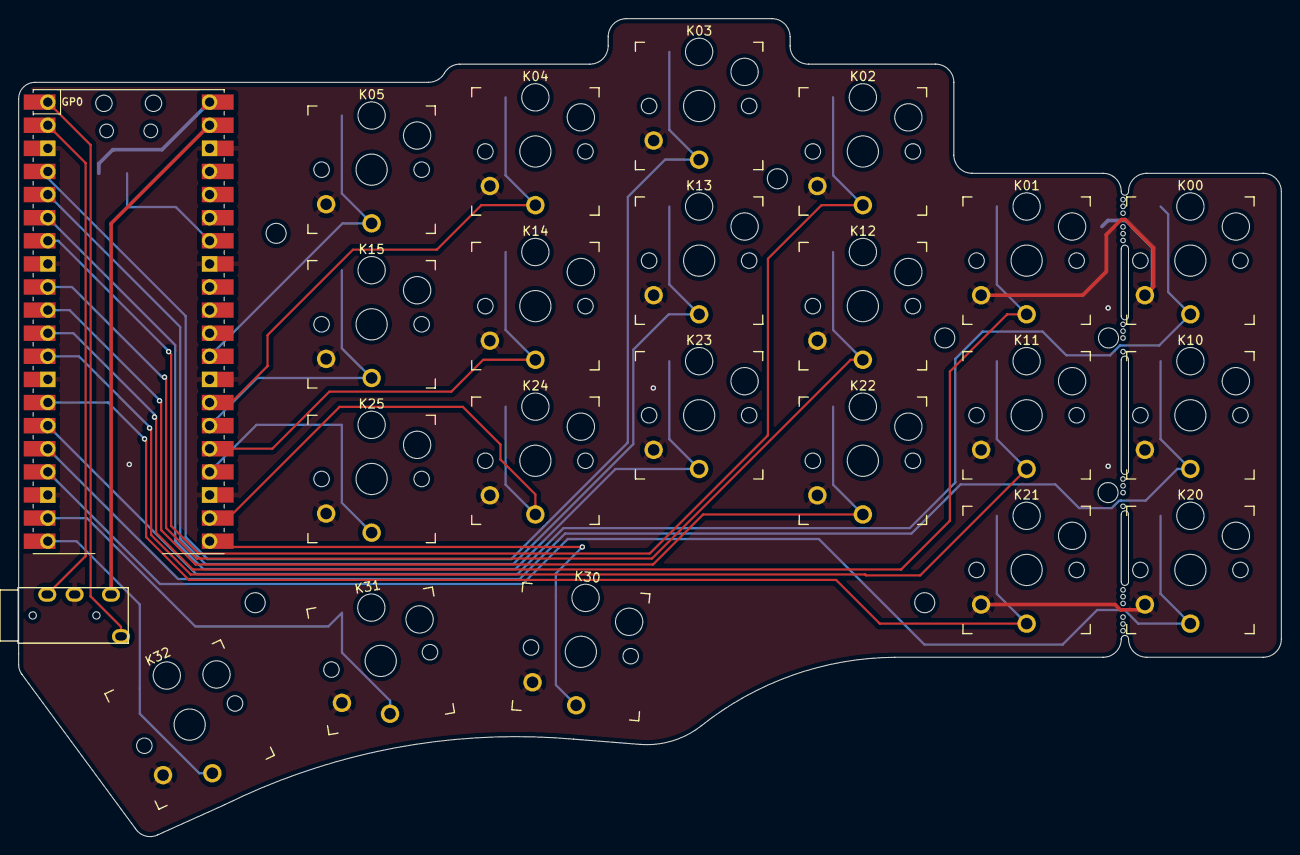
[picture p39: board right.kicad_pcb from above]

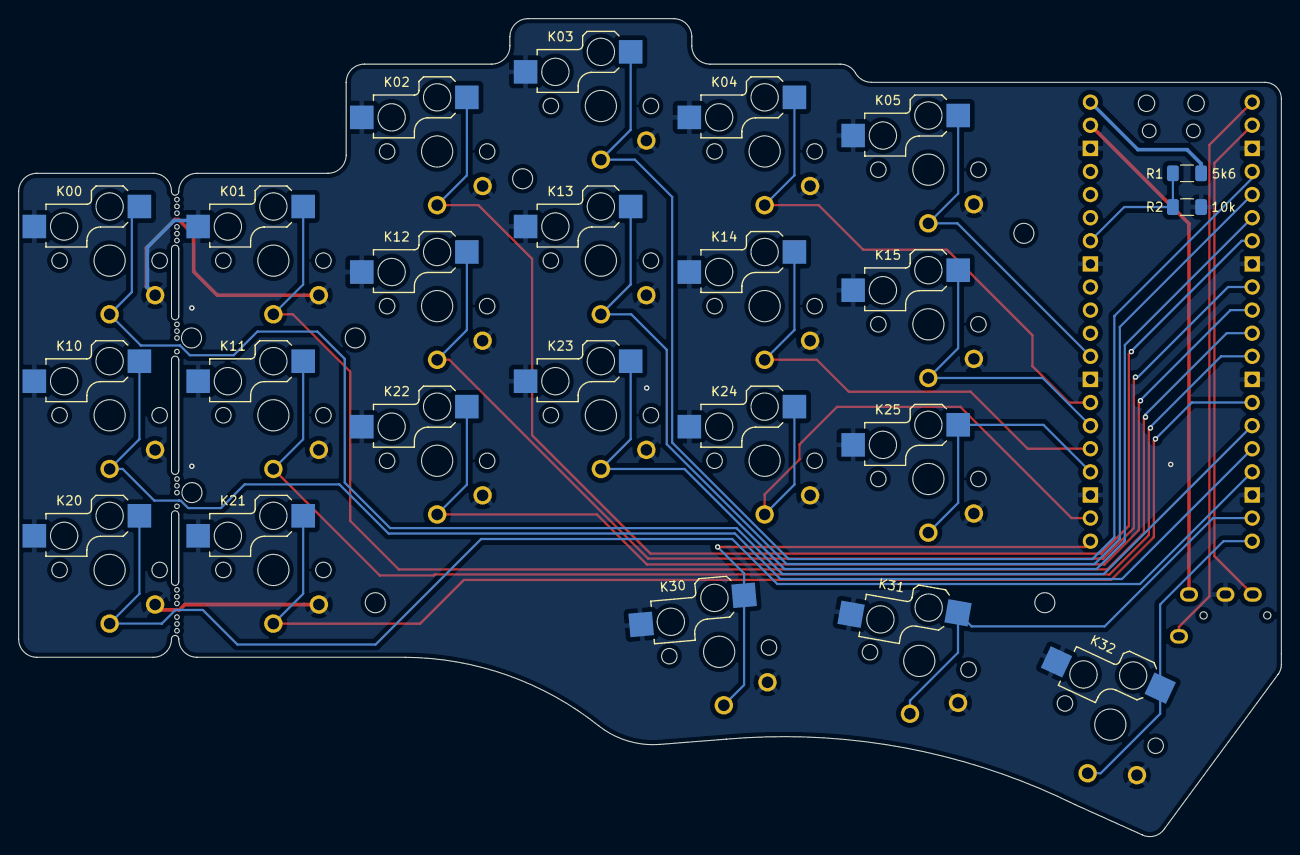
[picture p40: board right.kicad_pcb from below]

Board: 2 copper layers, 138.8 x 89.9 mm, 36 parts (13 on the bottom side), 27 nets.

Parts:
H1, H1#2, H2, H3, H4, H4#2, H4#3: MountingHole; MountingHole_2.2mm_M2-8mm
J1: TRRS; TRRS-PJ-320A
K00, K01, K02, K03, K04, K05, K10, K11, K12, K13, K14, K15, K20, K21, K22, K23, K24, K25, K30, K31, K32: KEYSW; Kailh_socket_PG1350_optional
MB1, MB2: MountingHole; mousebites_2
MB3, MB4: MountingHole; mousebites_3
R1: 5k6; R_1206_3216Metric_Pad1.30x1.75mm_HandSolder
R2: 10k; R_1206_3216Metric_Pad1.30x1.75mm_HandSolder
U2: Pico; RPi_Pico_SMD_TH

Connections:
/k00: K00.1, U2.15 (GPIO11)
/k01: K01.1, U2.11 (GPIO8)
/k02: K02.1, U2.7 (GPIO5)
/k03: K03.1, U2.4 (GPIO2)
/k04: K04.1, U2.27 (GPIO21)
/k05: K05.1, U2.29 (GPIO22)
/k10: K10.1, U2.16 (GPIO12)
/k11: K11.1, U2.12 (GPIO9)
/k12: K12.1, U2.9 (GPIO6)
/k13: K13.1, U2.5 (GPIO3)
/k14: K14.1, U2.25 (GPIO19)
/k15: K15.1, U2.26 (GPIO20)
/k20: K20.1, U2.17 (GPIO13)
/k21: K21.1, U2.14 (GPIO10)
/k22: K22.1, U2.10 (GPIO7)
/k23: K23.1, U2.6 (GPIO4)
/k24: K24.1, U2.22 (GPIO17)
/k25: K25.1, U2.24 (GPIO18)
/k30: K30.1, U2.21 (GPIO16)
/k31: K31.1, U2.19 (GPIO14)
/k32: K32.1, U2.20 (GPIO15)
GND: J1.3 (RING1), K00.2, K01.2, K02.2, K03.2, K04.2, K05.2, K10.2, K11.2, K12.2, K13.2, K14.2, K15.2, K20.2, K21.2, K22.2, K23.2, K24.2, K25.2, K30.2, K31.2, K32.2, R2.2, U2.3 (GND), U2.8 (GND), U2.13 (GND), U2.18 (GND), U2.23 (GND), U2.28 (GND), U2.33 (AGND), U2.38 (GND)
VBUS: R1.1, U2.40 (VBUS)
VCC: J1.2 (TIP), U2.39 (VSYS)
rx: J1.4 (RING2), U2.2 (GPIO1)
tx: J1.1 (SLEEVE), U2.1 (GPIO0)
vbus_sense: R1.2, R2.1, U2.34 (GPIO28_ADC2)

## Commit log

2026-09-21 Introduce Filo36 with verified layout and public design journal
    [left.kicad_pcb, right.kicad_pcb]
2026-09-21 Replace obsolete render with narrow revE CAD and assembly views
    [left-assembly.step, left-battery.stl, left-cradle.step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]
2026-09-21 Add an offline 3D assembly explorer with layers and GLB export
2026-09-22 Add editable FreeCAD assembly and open revF stack study
    [choc-envelope.step, filo36-left.kicad_pcb, filo36-left.kicad_sch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]
2026-09-22 Add configurable KLP keycaps, opaque display frames and English parts guide
    [Choc_Stem_Choc_Size_1.5U_Normal.stl, Choc_Stem_Choc_Size_1.5U_Saddle_H.stl, Choc_Stem_Choc_Size_1.5U_Saddle_V.stl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]
2026-09-22 Shape a continuous slim case and add printable themed frames
    [choc-envelope.step, filo36-left.kicad_pcb, filo36-left.kicad_sch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]
2026-09-22 Clarify themed relief height in the current 3D viewer
2026-09-22 Make the viewer visual with frame cards and component exploration
2026-09-22 Connect components to a persistent sidebar and remove orbit stalls
2026-09-22 Give themed frames shared multicolor finishes and recognizable previews
2026-09-22 Record public acceptance of the multicolor frame correction
2026-09-22 Follow the key contour with magnetic frames and dual battery support
    [choc-envelope.step, coupon-m2-thread.step, coupon-m2-thread.stl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]
2026-09-22 Record verified Contour and magnetic frame publication
2026-09-22 Derive a uniform case rim from the switch openings
    [coupon-m2-thread.step, coupon-magnet-base.step, coupon-magnet-frame.step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]
2026-09-22 Curve thumb contour and add persistent per-part viewer controls
    [coupon-m2-thread.step, coupon-magnet-base.step, coupon-magnet-frame.step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]
2026-09-22 Align case curves to keys and add interchangeable case designs
    [coupon-m2-thread.step, coupon-magnet-base.step, coupon-magnet-frame.step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]
2026-09-22 Record verified public case variants and contour delivery
2026-09-22 Add coordinated themes, selected print kits and nominal component models
    [D_SOD-123.step, SW_Hotswap_Kailh_Choc_v1.FCStd, SW_Kailh_Choc_V1.FCStd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]
2026-09-23 Synchronize nominal component models across CAD and KiCad
    [choc-envelope.step, coupon-m2-thread.step, coupon-magnet-base.step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]
2026-09-23 Align the frame corner with the case and document stack headroom
    [choc-envelope.step, coupon-magnet-frame.stl, left-assembly.step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]
2026-09-23 Complete current Flan36 identity and show only selected Outline logo
    [filo36-left.kicad_pcb, filo36-left.kicad_sch, filo36-right.kicad_pcb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]
2026-09-23 Verify Flan36 publication and refresh current documentation captures
2026-09-23 Add keycap palettes, creative frames and measured slim support options
    [left-assembly.step, left-battery-lead-0.stl, left-battery-lead-1.stl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]

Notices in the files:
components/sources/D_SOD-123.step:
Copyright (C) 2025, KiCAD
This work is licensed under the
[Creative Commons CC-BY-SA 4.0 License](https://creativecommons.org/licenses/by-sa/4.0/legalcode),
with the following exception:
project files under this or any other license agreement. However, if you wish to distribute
